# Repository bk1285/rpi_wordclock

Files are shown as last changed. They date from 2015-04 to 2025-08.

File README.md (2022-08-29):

## Software to create a Raspberry Pi based wordclock

### :vertical_traffic_light: Repo status

<p align="left">
 
 
 
</p>

### ✔️ Features
 * [Various language layouts](https://github.com/bk1285/rpi_wordclock/tree/master/wordclock_layouts)
 * [Various plugins](https://github.com/bk1285/rpi_wordclock/tree/master/wordclock_plugins) to
     * display the current time
     * get information on current temperature, sunrise, sunset, IP-settings, ...
     * play tetris (credits to [@mrksngl](https://github.com/mrksngl))
     * View a demo [here](https://youtu.be/wcLQDykRBbM?t=84)
 * RESTful, [swagger](https://swagger.io/specification/)-based API to access and control the wordclock functionality
 * [Documentation](https://rpi-wordclock.readthedocs.io/en/main/) on how to build the clock.
 * Remote control via webinterface (credits to [@FrankX0](https://github.com/FrankX0))
     * Control the wordclock with a browser within your local network
     * Linking the webinterface to your smartphones homescreen provides an app-like usage of the interface
     * Hardware buttons are not mandatory anymore.
 * Integration to your instance of [home-assistant](https://www.home-assistant.io/) using [this repository](https://github.com/bk1285/rpi_wordclock_for_homeassistant/)
 * Support for a brightness sensor (TSL2561)
  
### :books: Further reading
 * Exemplary builds are available at [pinterest](https://www.pinterest.de/berndkrolla/wordclock-gallery/)
 * [Roadmap](https://github.com/bk1285/rpi_wordclock/projects)

### 👏 Support 
 * Star this repo, if you like the project. 
 * Request a new feature by [opening a issue](https://github.com/bk1285/rpi_wordclock/issues), describing your feature request.
 * Contribute your code: [Learn how to create your own plugin](https://rpi-wordclock.readthedocs.io/en/master/doc_further_reading.html#adding-a-new-plugin)

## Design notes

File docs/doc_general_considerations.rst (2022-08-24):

.. _general_considerations:
General considerations
======================

.. _building_a_wordclock:
If you want to build a wordclock
++++++++++++++++++++++++++++++++

.. note:: This project is currently still in an experimental state:

  * The documentation contains the main steps to build a wordclock, but might not guide you through all steps in greatest detail
  * Depending on your language-dependent stencil-layout, you might need to adapt the software.
    Feel free to contribute here!
    Currently available:

      * Stancil layout and software:

          * german (including swabian and bavarian: Thanks to Timo and Euchkatzl)
          * english (Thanks to Alexandre)
          * dutch (Thanks to svenjacobi, resolution is 10x9. Therefore, not all plugins are supported!)
          * swiss
          * french
          * romanian (Thanks to Darius)
          * swedish

      * Stancil layout only (requiring some python-implementations: See wordclock_plugins/time_default):

          * italian
          * spanish
          * turkish

      * Further languages/stencil layouts can be created using the ''config-file'' and the script ''create_layout.py''

  * A final note: Throughout this project, you will assemble electronic components, which can possibly harm you or others (or destroy your hardware).
    It's therefore important, that you know, what you are doing: By assembling this clock, you act on your own risk!

* Hardware requirements:

  * A (wooden) sceleton to hold LEDs, stencil, RPi, etc...
  * A stencil providing the letters
    * Find an overview over the different layouts here: https://github.com/bk1285/rpi_wordclock/tree/master/wordclock_layouts
    * You can create them on your own: Special plotters can produce adhesive stencils, which you can glue onto a glas plane.
    * Consider, that you might need to invert the layout to have the adhesive surface on top to attach to the glas plate.
    * Possible options for ordering a stencil are:
      * https://www.ponoko.com/ (thanks to StefanCarton).
      * http://www.mikrocontroller.net/articles/Word_Clock (thanks to euchkatzl)
    * Further reading:
      * http://diskussion.christians-bastel-laden.de/viewforum.php?f=12&sid=b90281d4a392f47503e9b9fc15495b19

  * A frame to enframe the wordclock

    * Possible materials: Wood, alumnium, etc.

  * A LED-strip running at 5V (e.g. WS2812 B Stripe 5m 150 LED)

    * Assure, that the spacing of the LEDs on the strip is equal or greater than the spacing of the letters
      of your stencil. If the spacing is smaller, you will not be able to get your LEDs into the correct position.

  * A Raspberry Pi (e.g. Review B, including SD-card)
  * A wifi-dongle to connect your RPi wireless to your local network
  * A power supply (e.g. 5V 10A 50W LED Power Supply)

    * 5V are required. The current, which needs to be provided at max depends on the number and power consumption of you LEDs.

  * A user-interface to run the wordclock

    * e.g. 3 buttons (each requiring a 1k and a 10k resistor)
    * e.g. a capacitive touch sensor
    * ...

  * Some plugs to connect cables to the Raspberry Pis GPIO-pins
  * A micro-usb cable to connect the Raspberry Pi to the power supply
  * Optional: Hardware for levelshifting as oulined in https://learn.adafruit.com/neopixels-on-raspberry-pi/wiring and http://youtu.be/V9TwvranJnY?t=23m08s
  * Optional: A temperature sensor like an AM2302. To connect the sensor, an additial 10k resistor is required.

* You need to setup the software on your own

  * Some first documentation available here
  * This might require some python programming (to adopt the software to your needs)

* You should be ready to...

  * Setup the hardware (glueing, soldering, etc.)
  
    * Consider double connectors, if you want to minimize soldering efforts: https://github.com/bk1285/rpi_wordclock/issues/118
    
  * Setup a Raspberry Pi (raspbian)

    * Connect to the RPi via ssh
    * Install external dependencies of the wordclock project
    * Do some python programming (to adopt the software to your needs)

  * Contribute to this project

    * by sharing your implementations/improvements/enhancements/... ;)

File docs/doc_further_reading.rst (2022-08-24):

.. _further_reading:
Further reading
===============

.. _concepts:
Concepts and background
+++++++++++++++++++++++

.. _concept_WCA:
* WCA (Word Clock Array): The center matrix, without minute-LEDs and other stuff
.. _concept_WCA_DIMENSION:
* WCA_WIDTH, WCA_HEIGHT: Height and width of the WCA.

  * Part of the wordclock software are png-files, which need to fit to these values.
  * Currently available: 11x10 png-files.
  * Support for wordclocks with other resolution available (untested).

.. _concept_WCD:
* WCD (Word Clock Display): Includes any led attached to the wordclock (such as minutes, possible/future ambilights/etc.)
.. _concept_coordinate:
* Coordinates (or: WCA-coordinates): Can be 1d or 2d, used to adress a LED on the word clock array
.. _concept_index:
* Index (or: strip index): Used to adress a LED depending on the position on the LED-strip

.. _expanding_the_wordclock:
Expanding the functionality of the wordclock
++++++++++++++++++++++++++++++++++++++++++++

Remote control of the wordclock
-------------------------------

The wordclock comes with a REST-API to control the major functionality of the clock.

To access the API documentation, visit::

    http://wordclock-ip/api

Adding a new plugin
-------------------

You might be interested in expanding the wordclocks functionality by adding a new
plugin to the wordclock

To do so, you need to...

  * Think about the name of this plugin: E.g. `new_stuff`
  * Add a new folder `new_stuff` to the folder wordclock_plugins

    * Create a plugin.py-file with a class `plugin`, which has at
      least the following functions implemented:

      * __init__(self, config): You can use the config-object to pass data
        from the config-file for initialization purposes
      * run(): Run the actual plugin

  * For the actual implementation, you can access the provided methods of the class `wordclock_display`
    * If necessary you might extend it... ;)

  * Add an icon (with resolution 11x10 pixel) for the new plugin to the
    directory wordclock_plugins/`new_stuff`/icons/11x10/`logo.png`

  * Add a section `[plugin_new_stuff]` to the reference config-file (wordclock_config/wordclock_config.reference.cfg) and store there all necessary config-values in a way that they are suitable for all wordclock users by default and out of the box.
    * Even consider disableing your plugin by default..
    * Disabling is mandatory, if additional hardware is required to run the plugin.
  * Add the same section `[plugin_new_stuff]` to your local config-file (wordclock_config/wordclock_config.cfg), holding the (custom) values you want to have setup for your own clock.
    * Your plugin will extract config values from wordclock_config.cfg first. If they are not set their, it will default to wordclock_config.reference.cfg

  * Document everything properly, so that others (and maybe you as well) can later understand it... ;)

  * Commit your changes using git and consider to create a pull-request at https://www.github.com/bk1285/rpi_wordclock

  * Consider, that this repository uses nvie's branching model: http://nvie.com/posts/a-successful-git-branching-model/

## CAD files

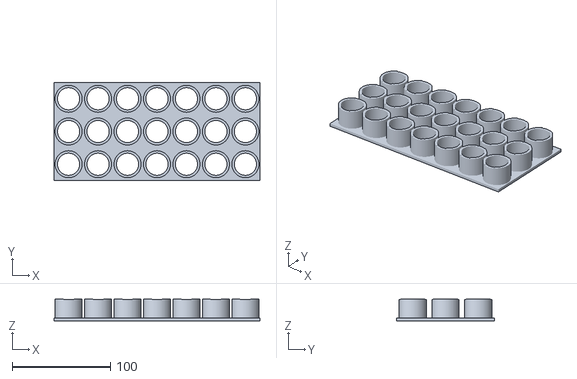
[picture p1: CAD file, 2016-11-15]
wordclock_layouts/wordclock_sceleton/LED-Base--LED-Mount-MM-Top.stl
209.7 x 99.7 x 22.0

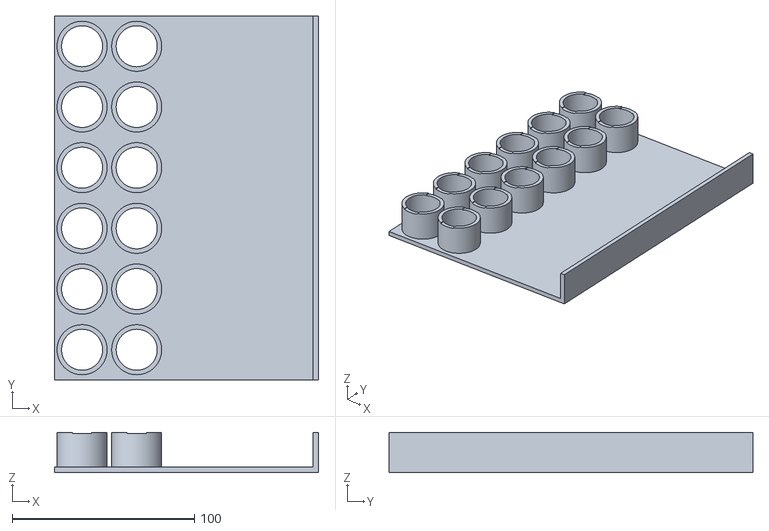
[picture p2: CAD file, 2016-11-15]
wordclock_layouts/wordclock_sceleton/LED-Base--LED-Mount-MR.stl
145.0 x 199.7 x 22.0

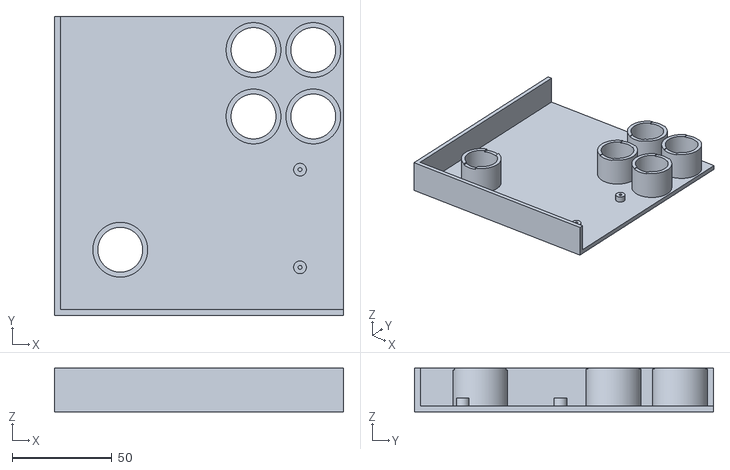
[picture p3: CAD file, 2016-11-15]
wordclock_layouts/wordclock_sceleton/LED-Base--LED-Mount-BL.stl
145.0 x 150.0 x 22.0

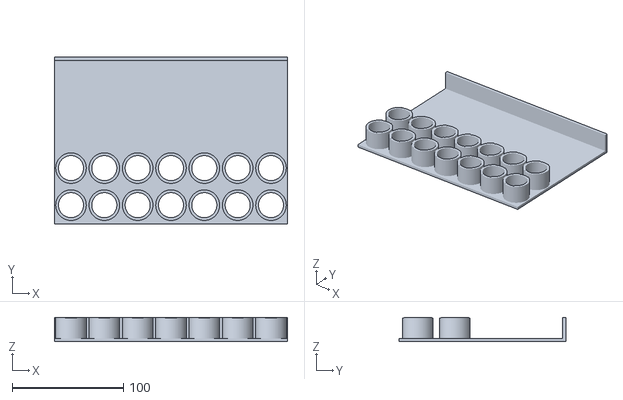
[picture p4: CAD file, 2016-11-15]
wordclock_layouts/wordclock_sceleton/LED-Base--LED-Mount-TM.stl
209.7 x 150.0 x 22.0

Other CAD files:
wordclock_layouts/wordclock_sceleton/LED-Base--LED-Mount-MM-Bot.stl
wordclock_layouts/wordclock_sceleton/LED-Base--LED-Mount-BR.stl
wordclock_layouts/wordclock_sceleton/LED-Base--LED-Mount-BM.stl
wordclock_layouts/wordclock_sceleton/LED-Base--LED-Mount-ML.stl
wordclock_layouts/wordclock_sceleton/LED-Base--LED-Mount-TR.stl
wordclock_layouts/wordclock_sceleton/LED-Base--LED-Mount-TL.stl

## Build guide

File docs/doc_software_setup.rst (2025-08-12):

.. _software_installation:

Software setup
==============

Setup your raspberry pi 
+++++++++++

Setup your raspberry pi (e.g. using Raspberry Pi Imager) by downloading and installing latest Raspian on the SD card.

During the installation process, configure the location according to your needs (incl. time zone, etc.) 

Set locales
+++++++++++

Since the config-file contains layouts for multiple languages, assure to have a utf-8 compatible locale after setting up your raspberry::

    echo $LANG

should return something, containing utf-8 at the end.
E.g.::

    en_US.UTF-8

If not, check this website, to adjust it: http://perlgeek.de/en/article/set-up-a-clean-utf8-environment

.. _wordclock_software:

The wordclock software
++++++++++++++++++++++

.. _3rd_party_deps_packages:

3rd party dependencies (packages)
---------------------------------

To install 3rd party dependencies (packages) enter in a terminal/commandline::

    sudo apt-get install git python3-pip python3-scipy swig fonts-freefont-ttf libopenjp2-7

.. _download_software:

Download software
-----------------

Clone the wordclock software to the directory ~/rpi_wordclock (to run the actual wordclock)::

    cd ~
    git clone https://github.com/bk1285/rpi_wordclock.git

.. _temperature_sensor:

(Optional) dependencies to readout temperature sensor
-----------------------------------------------------

To read out an temperature sensor (AM2302), which can additionally be connected to the raspberry via GPIOs, install the according dependencies:

These dependencies are http://www.airspayce.com/mikem/bcm2835/index.html

and::

    sudo pip install am2302_rpi

.. _brightness_sensor:

(Optional) brightness sensor
----------------------------

For using brightness sensor (tsl2561) i2c must be activated via raspi-config::

    sudo raspi-config

use the arrow keys to select 'Interfacing Options' and 'I2C' to tell the RasPi to enable the I2C interface. Then select 'Finish' and reboot the RasPi

Install adafruit-circuitpython-tsl2561 lib::

    sudo pip3 install adafruit-circuitpython-tsl2561

Set use_brightness_sensor config value to true and its address::

    # Set the brightness of the display (between 1 and 255)
    brightness = 200
    use_brightness_sensor = True
    sensor_address = 0x39

.. _3rd_party_deps_python:

3rd party dependencies (python packages)
----------------------------------------

To install 3rd party python dependencies (packages) run::

    cd ~/rpi_wordclock
    sudo pip3 install -r requirements.txt

.. _adopt_software:

Adopt software
--------------

To adjust the wordclock to your own settings, create and edit the file ~/rpi_wordclock/wordclock_config/wordclock_config.cfg

To start over, you might just copy the file ~/rpi_wordclock/wordclock_config/wordclock_config.example.cfg and adopt this file.

Note: Each plugin of the wordclock project has its own section in the config-file (create it, if needed, but not existant)

.. note:: If your wordclock has a stencil layout or display resolution, which is not supported yet, you might need to adopt the
  software by providing your own `wiring`-class (to the file wordclock_tools/wiring.py)

.. _run_software:

Run software
------------

To run the wordclock software (with adapted wiring and config-file) do::

    cd ~/rpi_wordclock
    sudo python3 wordclock.py

In case, the whole thing is not working as expected: Maybe the section :ref:`trouble-shooting` might help...

Run software without hardware in developer mode with wxPython
----------------------------

To run the wordclock software in developer mode without wxPython, install wxPython via::

    sudo apt-get install python3-wxgtk4.0

and set the developer_mode to True in the config-file::

    developer_mode = True

and run the software with::

    cd ~/rpi_wordclock
    sudo python3 wordclock.py

.. _run_software_on_startup:

Make software run on every startup
----------------------------------

Add the python-script to crontab by calling the command::

    sudo crontab -e

Add here::

    @reboot sudo python3 /home/pi/rpi_wordclock/wordclock.py

Access the wordclock via webinterface
-------------------------------------

Visit the wordclocks webinterface by entering the wordclocks IP to your browers address bar.

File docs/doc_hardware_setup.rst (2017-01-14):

.. _hardware_setup:
.. _hardware_setup_steps:
Hardware setup
==============

.. _skeleton_setup:
Skeleton setup
++++++++++++++

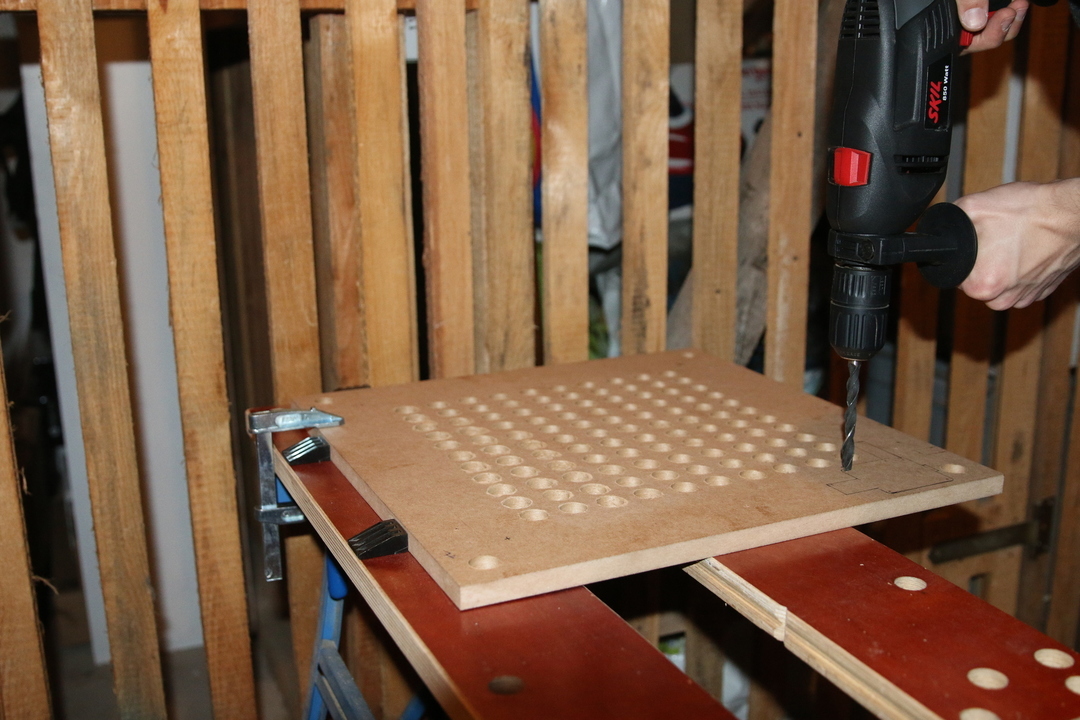
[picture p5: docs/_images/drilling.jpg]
Drilling


    According to the stencil layout, for each LED a hole needs to be prepared. The total number of 114 holes makes this pretty tedious.

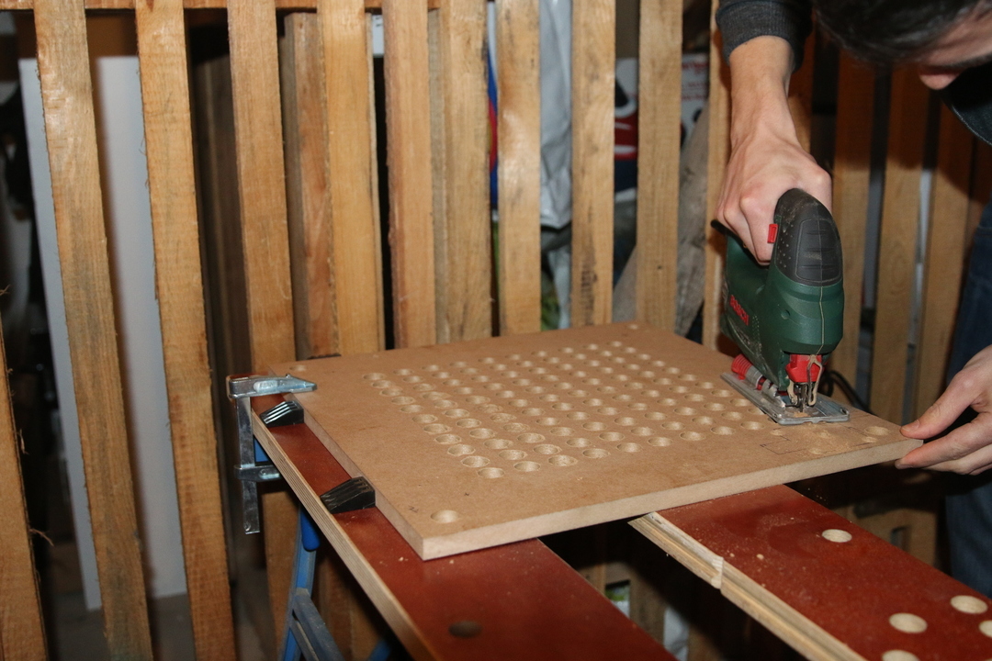
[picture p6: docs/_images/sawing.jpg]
Sawing


    To place the Raspberry Pi within the skeleton, some sawing is required...

.. _led_setup:
LED setup
+++++++++

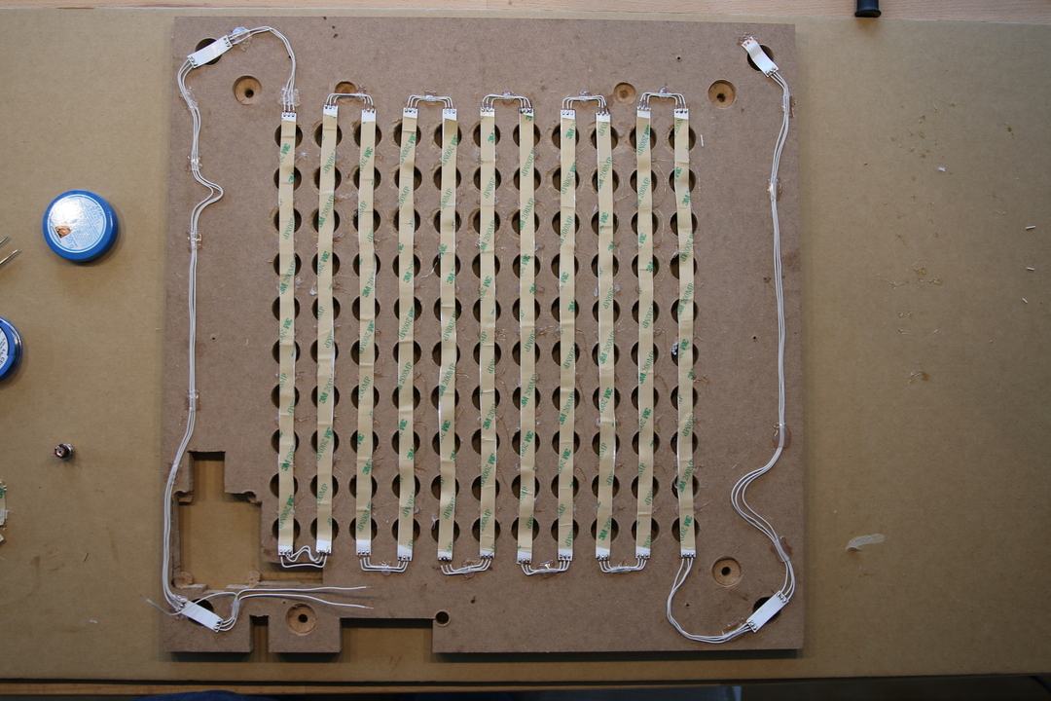
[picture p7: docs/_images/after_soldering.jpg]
After Soldering


    After soldering the LED strip, the clock looks like this. The soldering needs to be done according to the wiring layout. E.g. based on 11*10 letters:

.. _exemplary_wiring:
.. _concept_exemplary_wiring_layout:

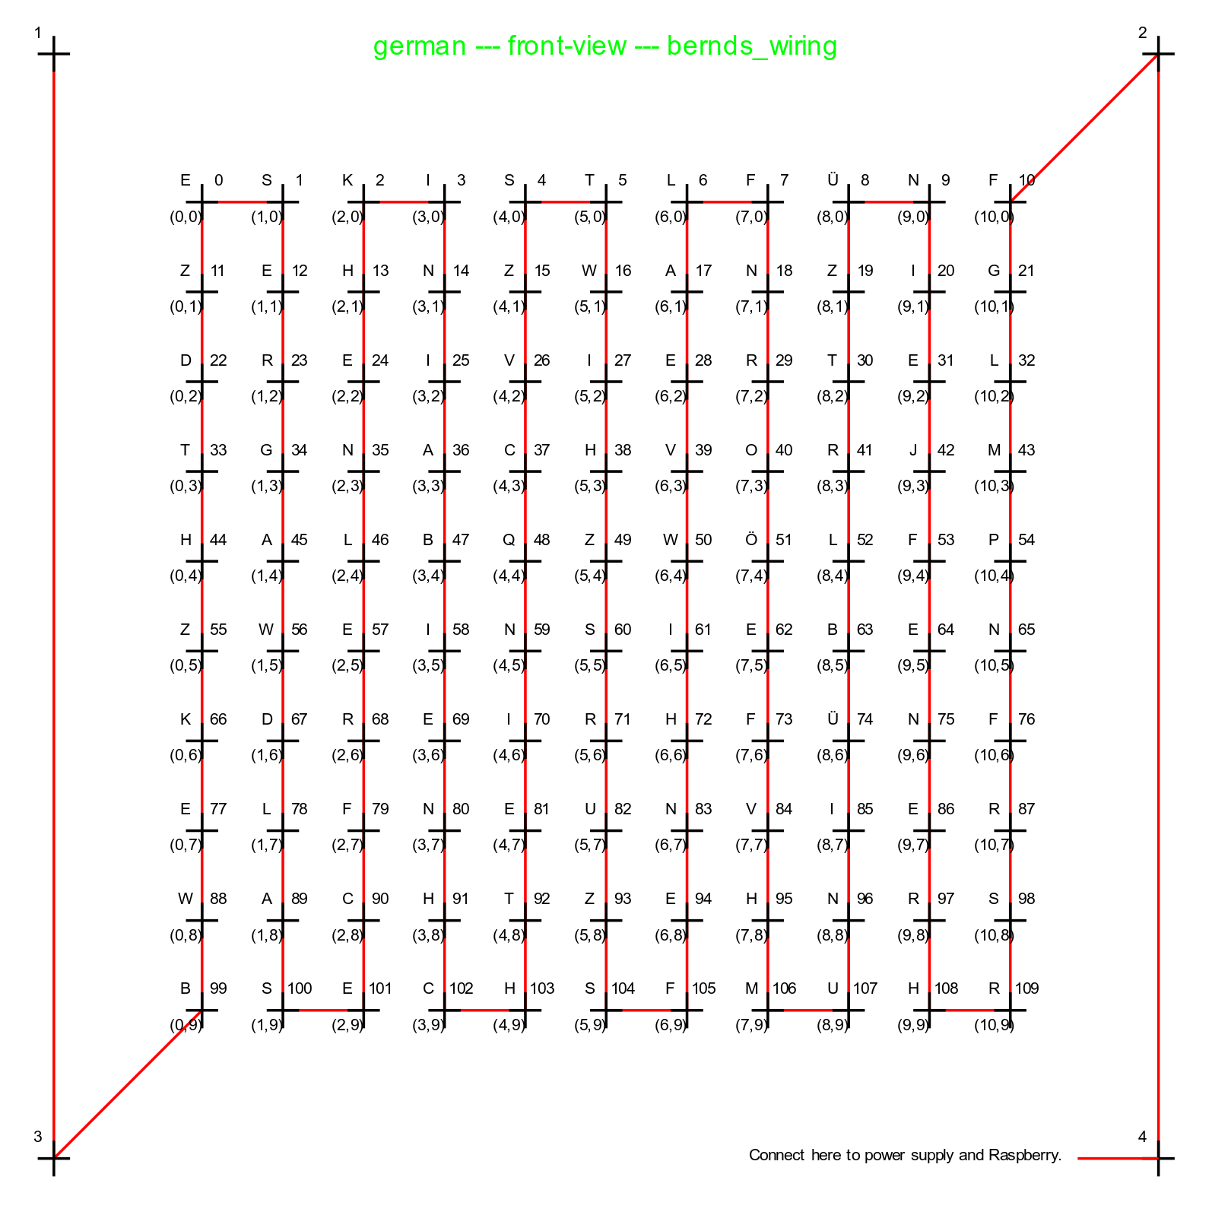
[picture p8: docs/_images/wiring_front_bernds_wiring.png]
Examplary wiring layout (front side)


    Further wiring layouts are `available <https://github.com/bk1285/rpi_wordclock/tree/master/wordclock_layouts>`_. Assure to connect the LED strip in the right direction. Little arrows indicate that along the strip.

.. _rpi_setup:
Raspberry Pi setup
++++++++++++++++++

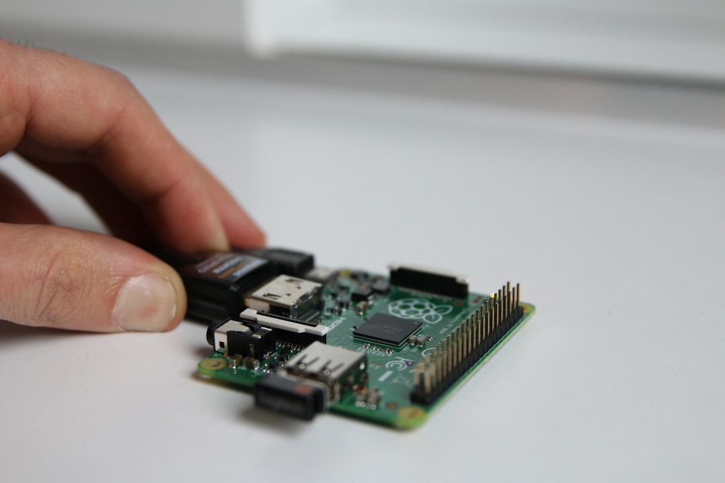
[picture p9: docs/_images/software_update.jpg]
Software Update


    Before you mount your raspberry inside the clock, install the latest Raspbian, connect it to your local wifi and ensure that you can ssh to it.

.. _button_setup:
Button setup
++++++++++++

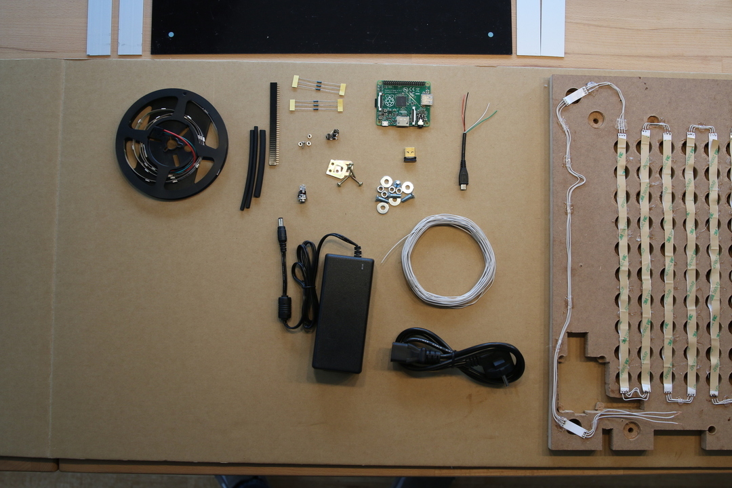
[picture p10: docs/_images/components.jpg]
Components


    At this stage, the displayed components are required for the further setup.

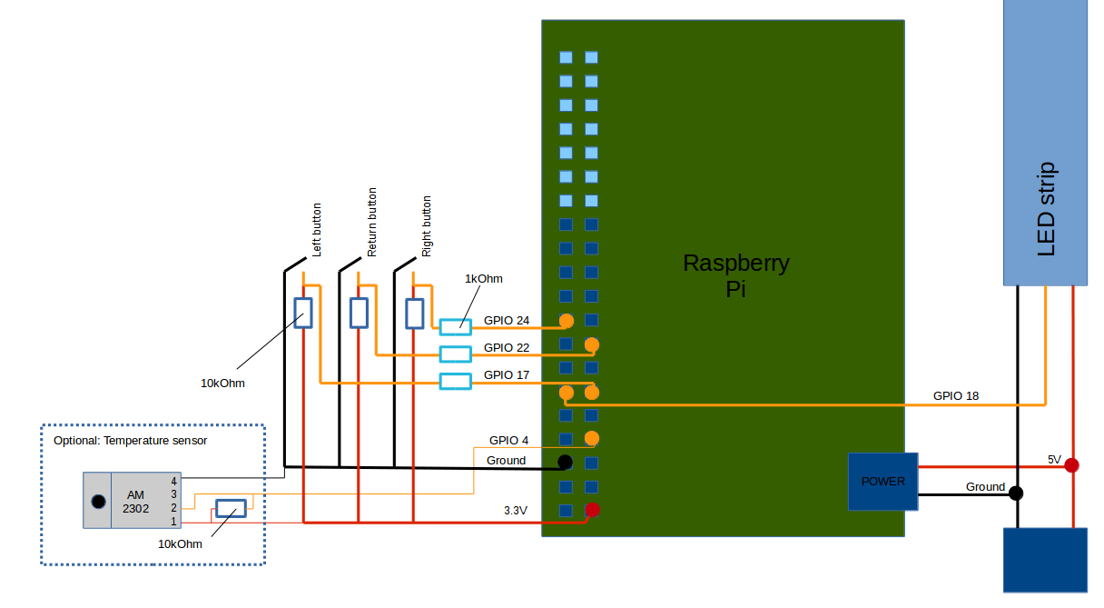
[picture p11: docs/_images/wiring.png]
Wiring concept


    Conceptual wiring layout to connect RPi, buttons, etc. See also `Power connectors <https://en.wikipedia.org/wiki/Coaxial_power_connector>`_, `USB-Pinouts <https://en.wikipedia.org/wiki/USB#Pinouts>`_

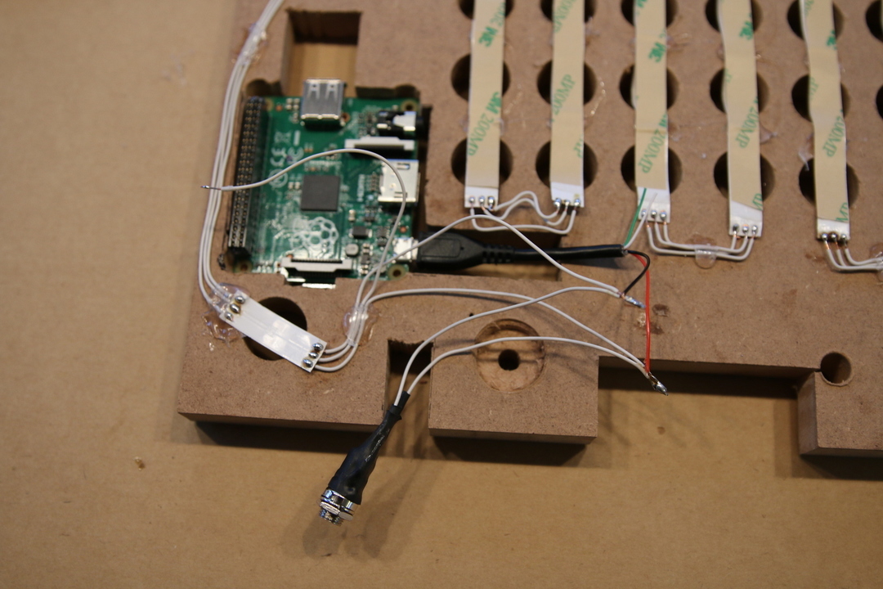
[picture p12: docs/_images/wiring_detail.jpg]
Wiring detail


    The connection of buttons, LED strip and power brings the wordclock close to its final hardware configuration.

.. _exemplary_button_wiring:

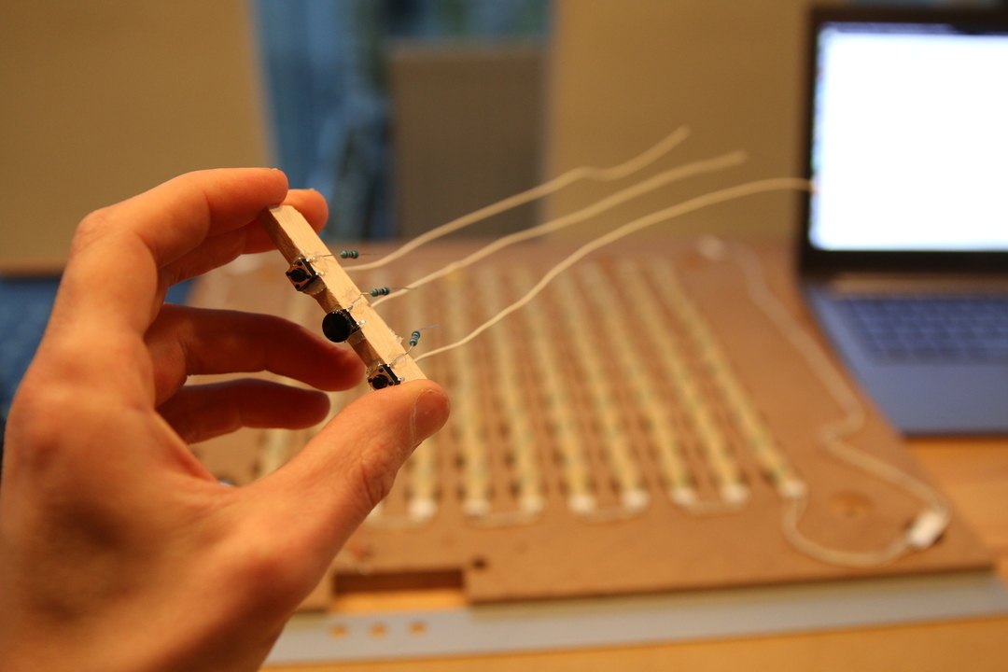
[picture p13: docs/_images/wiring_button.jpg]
Wiring button


    Buttons with attached resistors. The center button has already its final tip.

.. _stancil_setup:
Stancil setup
+++++++++++++

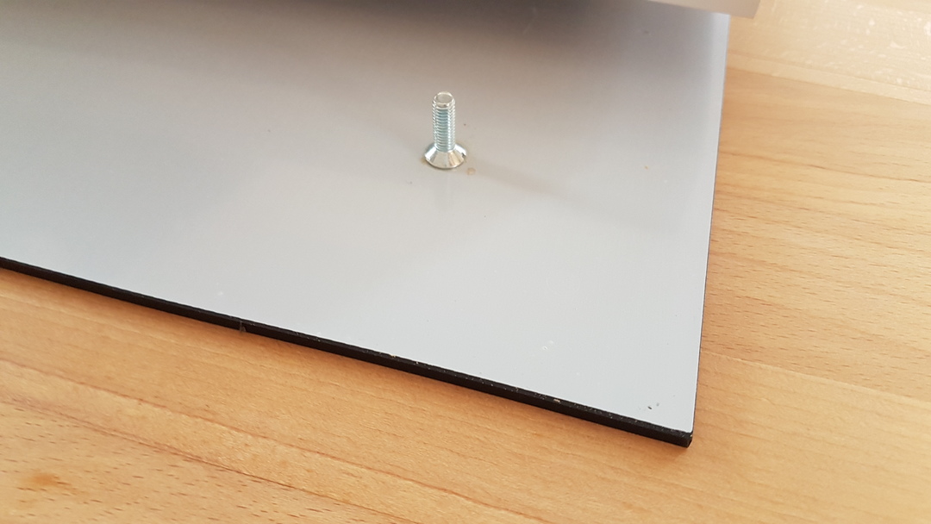
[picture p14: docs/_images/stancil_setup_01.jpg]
Stancil setup 01


    Fixation of 4 screws within the 4 corners of the stancil using two-component adhesive.

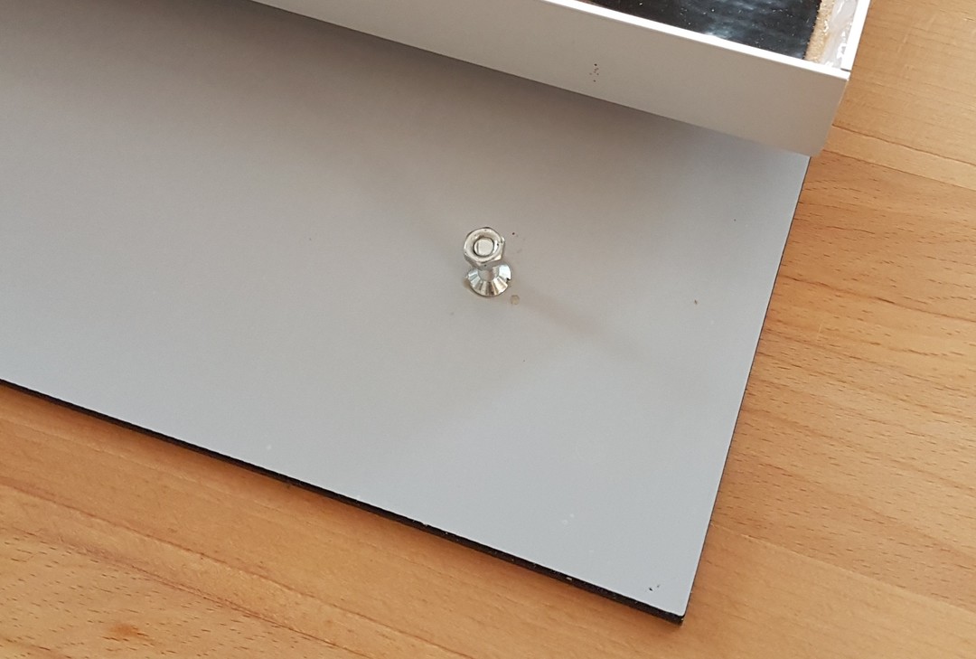
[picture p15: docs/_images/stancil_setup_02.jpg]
Stancil setup 02


    Allows to fix the stancil with screw-nuts to the sceleton.

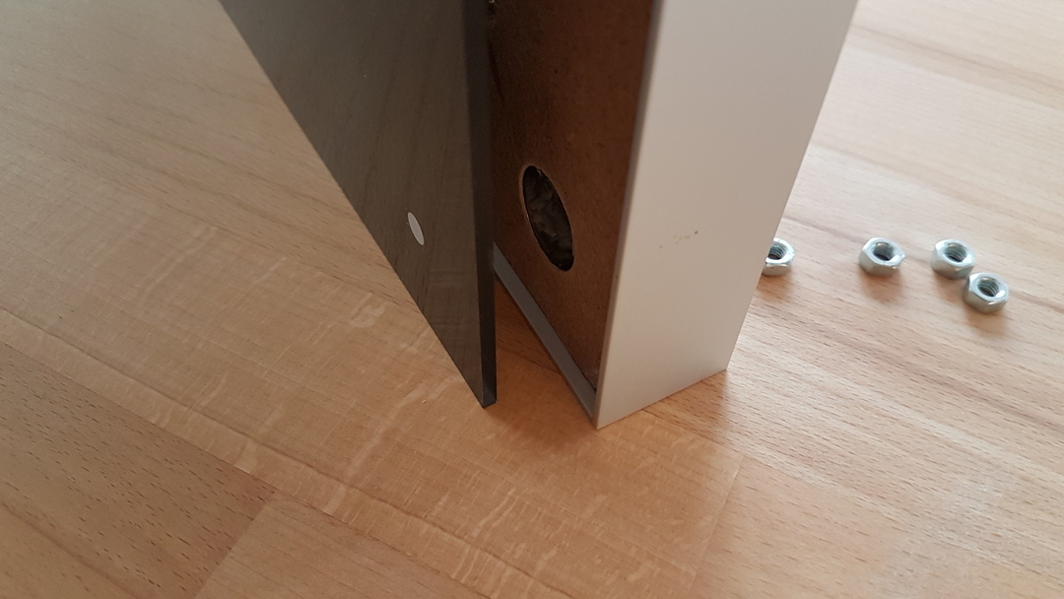
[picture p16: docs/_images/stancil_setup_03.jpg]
Stancil setup 03


    To increase stability, consider an overlapping of the frame to hold the major weight of the stancil.

.. _final_clock:
Final clock
+++++++++++

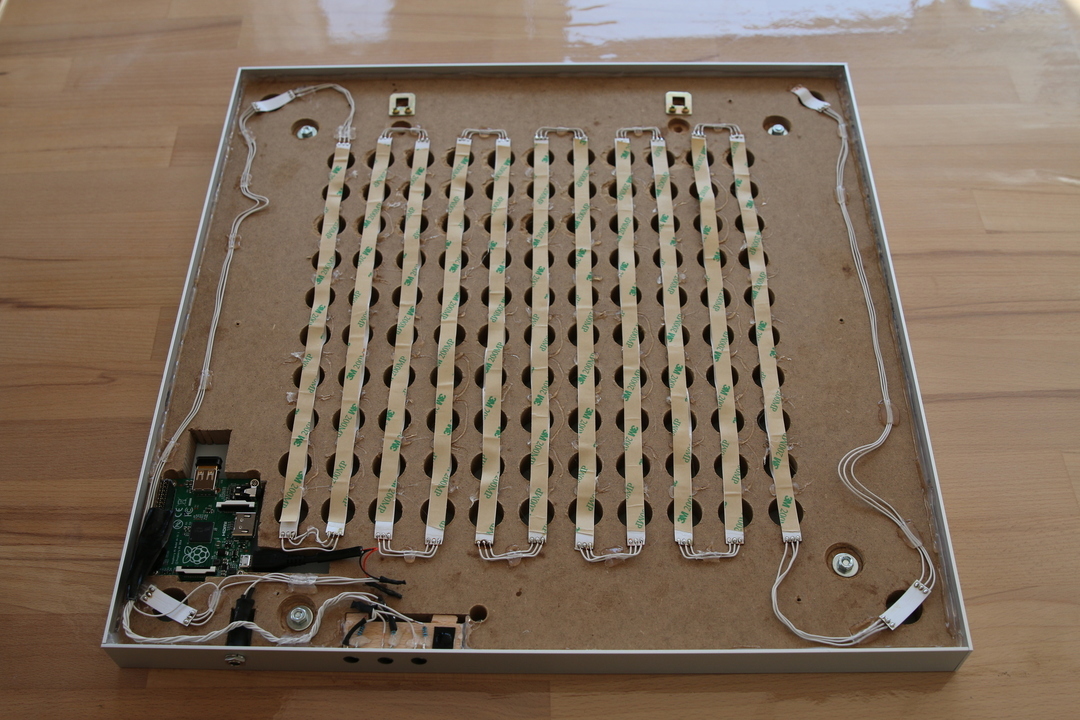
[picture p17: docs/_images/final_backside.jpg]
Final backside


    Backside of the final wordclock.

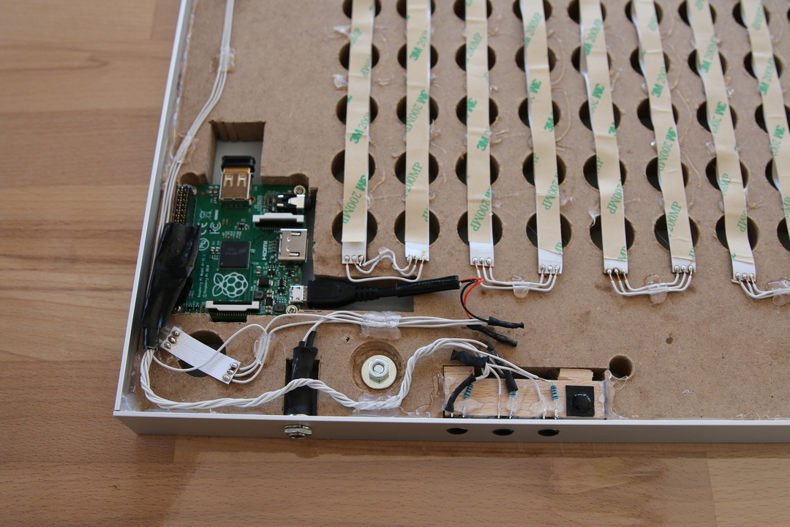
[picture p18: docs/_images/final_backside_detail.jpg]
Final backside detail


    Closeup of the final wordclock.

.. _video_documentation:
Video documentation on the wiring layout
++++++++++++++++++++++++++++++++++++++++

`Link to wiring documentation <http://youtu.be/V9TwvranJnY?t=8m43s>`_

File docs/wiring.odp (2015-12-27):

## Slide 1

3.3V

LED strip

Right button

Return button

5V

Left button

4

3

2

1

1kOhm

Raspberry Pi

10kOhm

GPIO 24

GPIO 22

GPIO 17

Optional: Temperature sensor

Ground

GPIO 4

GPIO 18

AM

2302

10kOhm

POWER

Ground

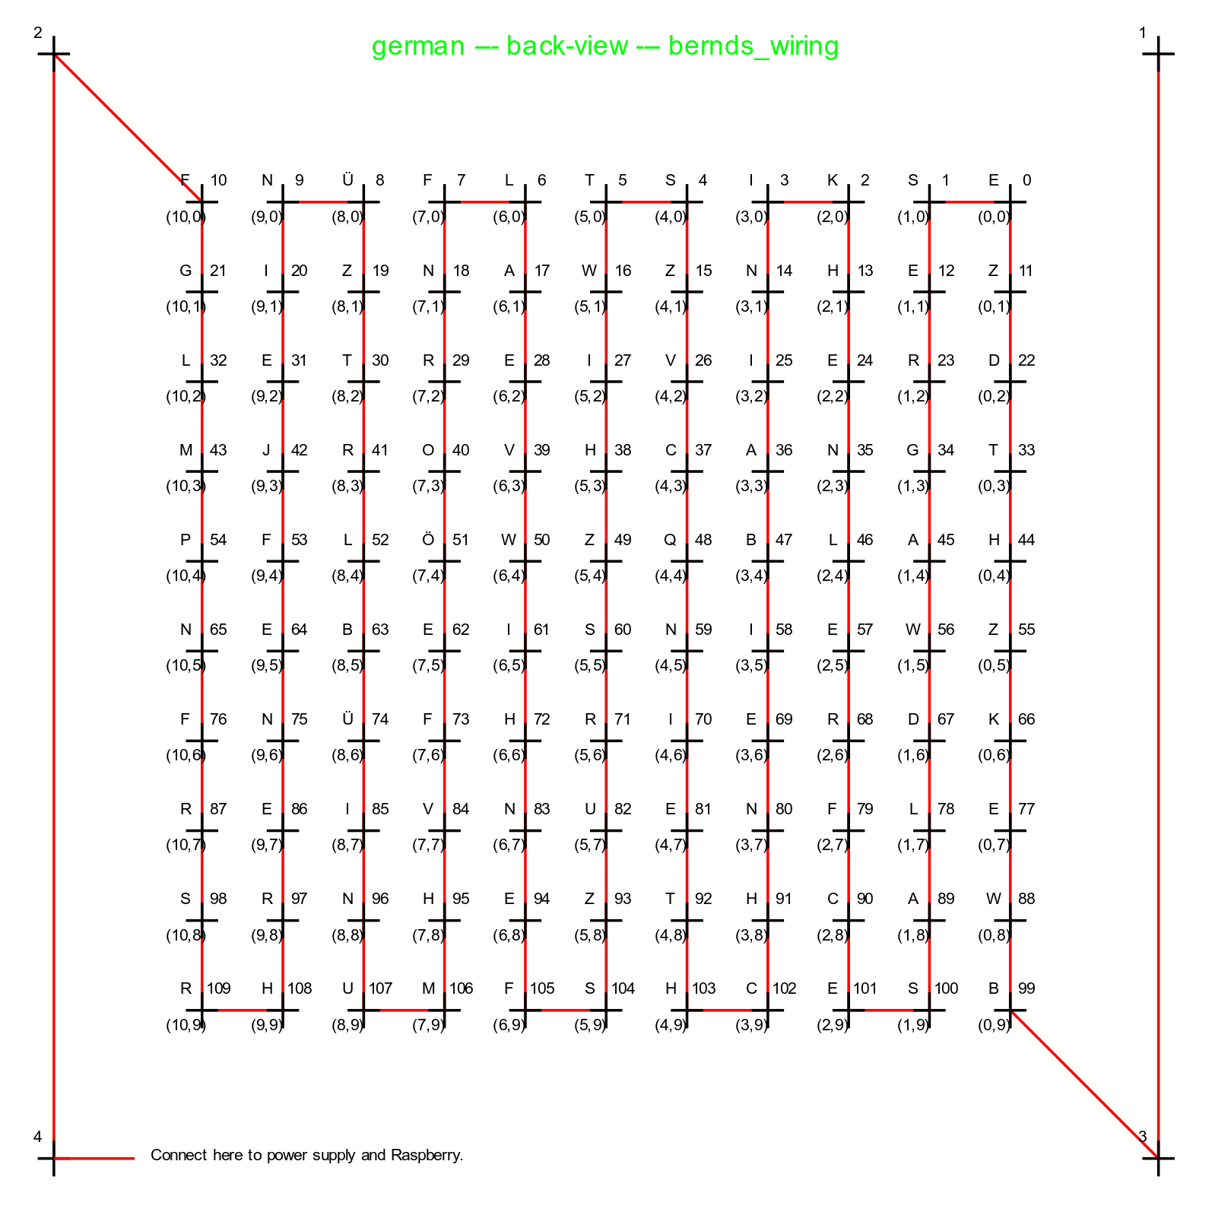
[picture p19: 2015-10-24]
docs/_images/wiring_back_bernds_wiring.png

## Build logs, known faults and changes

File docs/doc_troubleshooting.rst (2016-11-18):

.. _trouble-shooting:
Trouble shooting
================

Something is not working?

* The command::

    sudo pip install pytz astral feedparser pillow svgwrite freetype-py

  fails to install properly? If so, try to install further dependencies (thanks to SEBatHome)::

    sudo apt-get build-dep python-imaging libjpeg8 libjpeg62-dev libfreetype6 libfreetype6-dev

* The leds do not light up as expected?

    * It is important to have common ground for LEDs and RPi. Assure, ground is same for all of them (Thanks to euchkatzl).

    * Assure to connect the LED strip in the right direction. Little arrows indicate that along the strip (Thanks to euchkatzl).

    * Assure correct functionality of leds::

      cd ~/rpi_ws281x/python/examples
      vim strandtest.py # Set number of leds, pin, etc.
      sudo python strandtest.py

      The leds should light up now...

    * Disable the RPis soundcard (since it might interfere with the PMW-channel, sending data to the LEDs. Thanks to ELViTO12 for reporting)::

        sudo sh -c "echo blacklist snd_bcm2835 >> /etc/modprobe.d/alsa-blacklist.conf";
        sudo reboot;
        
    * In case the LEDs are flickering as shown in this video https://www.youtube.com/watch?v=UHxVS8SkXOU (Thanks to oxivanisher), consider the usage of a level-shifter to connect the GPIO-pin of the raspberry to the LED-strip. Further reading: https://github.com/jgarff/rpi_ws281x/issues/127 https://github.com/bk1285/rpi_wordclock/issues/38
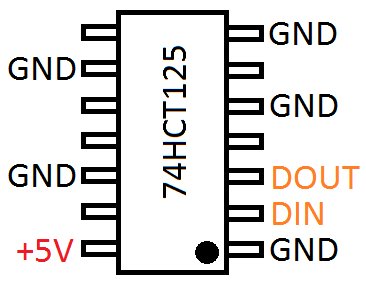
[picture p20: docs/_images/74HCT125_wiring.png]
Wiring of the a 74HCT125 level-shifter
    

* When starting the wordclock-script, "Pin 17 pressed" is logged all the time?

    To get rid of this message, you first need to finish the wordclock setup by attaching all 3 buttons to it.

    If you aim to run the wordclock without buttons, change the config-file settings as follows::

      [wordclock_interface]
      type = gpio_high

.. note:: The provided information might be completely unsatifying, leaving you here frustrated and annoyed without a working wordclock... :/

 However, if you have any issues during the setup, consider:

 * To update the provided documentation (or this trouble shooting section), as soon as you resolved your problem.

 * To report a software issue here: https://github.com/bk1285/rpi_wordclock/issues

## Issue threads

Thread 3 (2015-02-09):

Schaltungsvariante "spiegelverkehrt"

ghwc2015, 2015-02-09:
Hallo Bernd,

beim Zusammenlöten meiner Matrix habe ich nicht darauf geachtet, dass deine Bilder unter Concepts und wiring layout von hinten abgebildet waren.
Meine Variante benötigt daher eine spiegelverkehrte wiring.py

Habe diese erstellt und würde mich freuen wenn du die in den Code einbauen kannst - dann kann ich mit git zukünftige Änderungen mitbekommen.

```

class timos_wiring:
    '''
    A class, holding all information of the wordclock's layout to map given
    timestamps, 2d-coordinates to the corresponding LEDs (corresponding to
    the individual wiring/layout of any wordclock).
    If a different wordclock wiring/layout is chosen, this class needs to be
    adopted.
    '''

    def __init__(self):

        # LED strip configuration:
        self.LED_COUNT   = 114     # Number of LED pixels.
        self.LED_PIN     = 18      # GPIO pin connected to the pixels (must support PWM!).
        self.LED_FREQ_HZ = 800000  # LED signal frequency in hertz (usually 800khz)
        self.LED_DMA     = 5       # DMA channel to use for generating signal (try 5)
        self.LED_INVERT  = False   # True to invert the signal (when using NPN transistor level shift)

        self.WCA_WIDTH   = 11      # Wordclock array width
        self.WCA_HEIGHT  = 10      # Wordclock array height

    def setColorBy1DCoordinates(self, strip, ledCoordinates, color):
        '''
        Linear mapping from top-left to bottom right
        '''
        for i in ledCoordinates:
            self.setColorBy2DCoordinates(strip, i%self.WCA_WIDTH, i/self.WCA_WIDTH, color)

    def setColorBy2DCoordinates(self, strip, x, y, color):
        '''
        Mapping coordinates to the wordclocks display
        Needs hardware/wiring dependent implementation
        Final range:
             (0,0): top-left
             (self.WCA_WIDTH-1, self.WCA_HEIGHT-1): bottom-right
        '''
        if x%2 == 0:                    # even columns 0,2,4...
            pos = (x)*self.WCA_HEIGHT+y+2               # last +2 for the minute LEDs before the WCA
        else:                           # odd columns 1,3,5...
            pos = (self.WCA_HEIGHT)+(self.WCA_HEIGHT*x)-y+1

        strip.setPixelColor(pos, color)

    def mapMinutes(self, min):
        '''
        Access minutes (1,2,3,4)
        Needs hardware/wiring dependent implementation
        This implementation assumes the minutes to be wired as first and last two leds of the led-strip
        '''
        if min == 1:
            return 1
        elif min == 2:
            return 113
        elif min == 3:
            return 112
        elif min == 4:
            return 0
        else:
            print('WARNING: Out of range, when mapping minutes...')
            print(min)
            return 0

    def getMinuteIndices(self):
        '''
        Returns all indices of the led strip, which are representing minutes
        .. todo:: Merge/unify with mapMinutes
        '''
        return [1, 113, 112, 0]

    def getWcaIndices(self):
        '''
        Returns all indices of the led strip, which are part of the word clock array
        '''
        return range(2, self.LED_COUNT-2)

```

bk1285, 2015-02-17:
Hi Timo,
if I got it right, is this issue related to https://github.com/bk1285/rpi_wordclock/issues/4
Therefore, I'll close this one, adding your wiring layout.
For future contributions I obviously prefer pull requests instead of sourcecode via issues... ;)
Regards,
Bernd

Closed 2015-02-17.

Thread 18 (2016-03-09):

Remote Control

euchkatzl, 2016-03-09:
I have created an experimental iOS App to Control the Wordclock from your smartphone. (Needs Xcode to Compile and Run)

Check it out here :

https://github.com/euchkatzl/RaspberryWordclock-iOS

bk1285, 2016-03-12:
Hi @euchkatzl ,

That's a great thing! I like it a lot! I shortly inspected your repository and saw, that some diff needs to be applied to the wordclock installation in order to make it work with the app...

Maybe we should team up to modify the wordclock to be iOS-ready by default... ;)

I'd even consider one "global" solution, which considers android as well. I'll take a closer look, if I find the time: Probably not within the next two weeks... :/

Meanwhile I leave this issue open.

Best,
Bernd

euchkatzl, 2016-03-14:
I'm am already working on a better solution.

The best solution will be a simple web site hosted by the pi accessible through a normal web browser.

I have little experience with that but i will get this work i think.
I will post it here as soon as possible.

Would be great if you could apply this patch by default.

euchkatzl, 2016-03-16:
I have made the Web based solution.
Check it out : https://github.com/euchkatzl/RaspberryWordclock-RemoteControl.

My main Problem is that i cannot test all this stuff because the clock was a present for christmas and i have no possibility to give it a "live" try at any time. I will build mine in the course of this year.

Will be great if we get this working.

euchkatzl, 2016-10-02:
Hi Bernd,
finally  created my own clock and get the remote stuff working. (On all devices ;) )

Can you please check out the changes in my Repository and perhaps include it ? (https://github.com/euchkatzl/RaspberryWordclock-RemoteControl)

It is really cool playing tetris with controlling from your smartphone ;)

bk1285, 2016-10-02:
Awesome! I need to check this out!

I'll definitely add it to the repository! But tell me: Do your virtual GPIOs interfere with the real buttons?

Regards!
Bernd

euchkatzl, 2016-10-02:
No. The real buttons work like before. They have the same functionality.

Look at wordclock_interface.py file.

It is just and "or" clause.

SimJaaenis, 2016-11-15:
Does it work at the moment? I tried it, but when I start the Webiopi-deamon I'm not able to use any button at the clock or at the web-interface.
I read, at the RaspberryWordclock-RemoteControl-project, you are using the Pins 7, 8 and 11.
If you are referring on this wordclock-project, shouldn't it be Pins 11, 15 and 18?

euchkatzl, 2016-11-15:
Yes it works for me !
I have choosen GPIO's 7,8 and 11 (that is not the pin number! There is a difference. pin numbers for the Remote Control are 23,24 and 26). Of course you can use any other GPIO's. But then you have to modify the patch file and the index.html in my repo.
GPIO 18 you cannot use because it is used for the LED signal.

What did you do so far ? Did you see my Web Interface that i have written ?
Have you applied the patch file to the wordclock repo ? It is not included by default

SimJaaenis, 2016-11-16:
Referring to this image [http://rpi-wordclock.readthedocs.io/en/latest/_images/wiring.png](url) I did my wiring.
Left button is at GPIO 17 = Pin 11, return button is at GPIO 22 = Pin 15 and  the right button is at GPIO 24 = Pin 18.
Just to understand the functionality: Do you use the same GPIO's like the original (hardware) buttons, or are the virtual "buttons" just referring to the same functionality as the hardware buttons?

Yesterday I saw your edited index.html with the "wordclock" link. Now I'm seeing the default page, without the link. I tried to many different things to get this to work, now its better if I clean install my wordclock.

euchkatzl, 2016-11-16:
The virtual buttons have only the same functionality as the original buttons.

But I think there is a wrong path file in the repo.
I will check this as soon as i am at home today.

euchkatzl, 2016-11-16:
i created a fork with all the changes :
https://github.com/euchkatzl/rpi_wordclock (Commit : 0846e15d1ce63b189e55d58257882202ac61cf84)

euchkatzl, 2016-11-16:
You can simply clone ist to another folder.
Then link the fontdemo.py and the this should work if you have configured webio-pi the right way.

I have tested this just right now ;)

bk1285, 2016-11-16:
Great, @euchkatzl,  Just merged it back: https://github.com/bk1285/rpi_wordclock/pull/39

bk1285, 2016-11-16:
@SimJaaenis can you confirm, if it works. If this is the case, I'll close the issue.
Bernd

SimJaaenis, 2016-11-17:
Short answer: Now It works! Thanks a lot!
Long answer: @euchkatzl In my case, I thought the htdocs-folder is the default of WebIOPi's-Webinterface, but WebIOPi doesn't use the "../htdocs/index.html" as default. After I tell WebIOPi in its config to do that, it worked.
I wondered a few times, why my browser didn't show any change of the index.html in 'htdocs'. After I changed the config-file to exactly that directory, it worked.

`# Use doc-root to change default HTML and resource files location
doc-root = /home/pi/WebIOPi-0.7.1/htdocs`

Thanks a lot! Now I can play Tetris :D

A little improvement proposal:
an inactivity-time of the virtual buttons of 0.2 secs, after a virtual-button was pressed, would be good. Just like the hardware Buttons ;)

euchkatzl, 2016-11-17:
Great !
@SimJaaenis
The timeout is 150 ms (look in the index.html). For the virtual buttons we have to simulate this.
Try setting it to 200 an report if it improves your stuff.

SimJaaenis, 2016-11-20:
I think the problem is my WiFi.
I changed the position and now it works better without any code changes.

bk1285, 2017-01-04:
Refering to https://github.com/bk1285/rpi_wordclock/issues/57

... whats the best way to go? If we find a fix for the current master branch, which leaves the virtual pins enabled, we're done at first place.
In the long run we could probably consider something more advanced...

bk1285, 2017-01-04:
Maybe we could also consider the work of @fecub which looks preety promissing...  https://github.com/fecub/rpi_wordclock/commits/remote_controller

;)

Tihmann, 2017-01-08:
How does @fecub modification work ? Is it setting up a server ? Tried to figure it out from the branch....

euchkatzl, 2017-01-09:
@Tihmann
Can you tell me why Web IO Pi is not working anymore ?

bk1285, 2017-02-04:
Last weekend, I found the time to team up with @mrksngl, who is giving lectures in multi-threading, event-handling, etc. As a result of 14hrs of hacking, the wordclock will soon be ready to take not only the buttons as input anymore... Great work, @mrksngl :)

Checkout https://github.com/bk1285/rpi_wordclock/tree/develop for further details or take a look at https://github.com/bk1285/rpi_wordclock/projects/2 for the further agenda.

euchkatzl, 2017-02-07:
Hi @bk1285 ,

That is great work ! Thank you for that.
I've testet the socket connection with a litte Qt Programm. Seems to work fine !

But there is a little more work to do so that we can use it as Remote Control !

1. Add a command for Button press (e.g. sending  "BUTTON_PRESS" : 18)
    a.  I think that will not be the problem and very easy to implement
2. To work with any devices we need an web interface (like the page i have written)
    a. This page must be hosted on the pi to interact with the socket connection
    b. We need a web server on the pi
         1. Host it directly via python code ( i dont know if this is possible)
         2. Host it via node (i think this is the easiest solution)
         3. Set up an apache Web Server for usage of php
3. Without a new Webinterface the socket connection could only be used directly in an app that we habe to write for ios and android. I can do this but then we need to upload it to the app stores so that anybody can use it ( could be a problem . Especially on ios)

So tell me what you think the best solution could be !? I can do the Web Interface work if you want to.

fecub, 2017-02-07:
Hi @bk1285,

thank you Bernd. Thank you for this awesome clock project.
I wanted to report you, if I'm done with my work :) but you discovered me earlier :)

Ok what I have done:

-  as @Tihmann says. I set up an server and intergrated in the project.
- the remoting is working on main  menu, time_default and matrix plugins
- ... the other plugins need to modified for remoting
- I wanted the gpio button and remote controller things seperated. But this forcing me to add two or more lines of code

1. For example you need to pass the socket class on every plugin
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
mrksngl, 2017-02-07:
Little preview of my current work (yes, I emulated everything in here) (yes, GTK has some problems with umlauts): https://www-user.rhrk.uni-kl.de/~mengel/wclremote.webm

euchkatzl, 2017-02-07:
@bk1285 @mrksngl

I totally agree on the "bad design" points ! The solution now is a much better approach !

For App Developments i can help you since i'm am an app developer (iOS and Android) in my main job ;)

Video of the App looks great ! How did you get that simulated wordclock interface ? Can you explain that (perhaps in another ticket)

For the Android app you are right ! You can distribute this without any App Store. But in iOS this is not possible.

So the best approach is to write a new Webinterface which works with both systems (and also Windows Phone). I can do this as soon as you publish your Android Code.
Moved discussion for this :
https://github.com/bk1285/rpi_wordclock/issues/59

mrksngl, 2017-02-07:
@euchkatzl

Glad to hear we have an app expert:
1) I don't like GUI development at all (though I have to admit that android has some nice concepts and there is a really cool tool support in android studio)
2) I just started android development, so I read some guidelines (you know it: android is a beast) and realized the project "my own way". Especially data exchange between the network and the UI thread is maybe not the Android way.

The simulated wordclock interface is just a GTK window with a 11x10 table (plus the dots for the minutes), having 114 labels, each displaying one character. I replaced (it's a huge hack!) everything that has to do with the LED strip with GTK code recolouring the labels. The button events are generated by keyboard events. I could publish it, but only in a separate branch, because right now it breaks normal operation. This is another issue in refactoring the project.

euchkatzl, 2017-02-07:
1. Yes Android is very easy for GUI things. Much better than iOS.
2. I can tell you that when i got a look at your Code. For me it would be nice to get an idea how to talk to the socket ;)

The better approach would be using PyQt for the simulated GUI. So it works also on non Linux Systems (maybe). But would be great if you could publish it ;)
Thank you !

bk1285, 2017-11-03:
Hi all, just finished an experimental version of the webinterface: https://github.com/bk1285/rpi_wordclock/tree/feature/webpy
There are still some minor issues to fix, before I merge to develop, but maybe you want to give it a try (after installing web.py). Please note, that this currently requires the wordclock.py to be started within the directory, it's located in: /home/pi/rpi_wordclock.

Best,
Bernd

Sauerland1973, 2017-11-09:
Hallo Bernd,
habe dein Projekt noch ein wenig "verfeinert" ;-) Ich habe eine Matrix von 15 x 15 LED....
nun würde ich gerne auch das Web interface nutzen, allerdings bekomme ich diese Fehlermeldung:
File "/home/pi/rpi_wordclock/wordclock_interfaces/web_interface.py", line 1, in <module>
    import web
ImportError: No module named web

Was mache ich Falsch?
LG aus dem Sauerland

euchkatzl, 2017-11-09:
Du musst WebPy installieren :
http://webpy.org/install

Sauerland1973, 2017-11-09:
Oh, das ging schnell, vielen Dank für die schnelle Antwort!
Ich werde es direkt mal ausprobieren ;-)
LG

Closed 2018-01-04.

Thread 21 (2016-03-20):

Need help

christiankrueger16790, 2016-03-20:
Hi all,

Sorry, if i write down my comment into the wrong directory, but didn´t found a directory for questions.

I´m also want to build a RPi wordclock. I´ve got a rpi a+ model with ws2812 led controller.
Unfortunately, I'm still a little inexperienced in matters of led-controlling with a raspberry pi.
I´ve finished the hardware setup and installed the software like the description.
But when i´m start the wordclock software the leds, do nothing.
I´ve tried to controll the strips with the strandtest.py software, but the leds do also nothing.
Only two leds in the middle of the strips lights up.
I thought i´ve got a misstake in the wiring, but i´ve checked all the solder joints and i think there look good.
I tried to wired up the wordclock with a 74AHCT125 level converter and a 1N4001 diode like the description of (adafruit).

Can you give me an idea, what i also can check.
Sorry about my stupid questions and bad english!
I hope you can help me.

bk1285, 2016-03-20:
Hi @christiankrueger16790

hm... What do you mean with ws2812 controller? You just need to connect a WS2812B led-stripe to the Raspberry.

Ideas from my side:
- ensure to have a WS2812B led strip (no WS2812: This is untested and possibly does not work)
- ensure to have the correct number of LEDs set to trigger (adopt the strandtest.py)
- ensure to have a power supply, which supplies enough power: With 10A at 5V, you're on the save side.

If you find the solution, maybe just post it here, so that others can benefit as well. Hope that helps. Otherwise, just reopen the issue.

Regards,
Bernd

christiankrueger16790, 2016-03-22:
Hi Bernd

Sorry, but it is a ws2812B led stripe, not only ws2812.
I set the correct number of leds (114 counts).
I´ve got a power supply of 5V/10A, i think that´s ok.

Do you have another idea?

Can create and upload a zip file of your actual wordclock image with win32 disk manager, is it possible?
Because I want to ensure, that i don´t forgot any packages.

Regards
Christian

bk1285, 2016-03-22:
Hm.... maybe try to go through the installation steps again: If you reinstall the packages, you might identify missing dependencies...

Regards,
Bernd

Closed 2016-03-20.

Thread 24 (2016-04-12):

stencil/clock face

whybot, 2016-04-12:
Hello,
Are you able to provide link(s) to online vendors who can produce customised stencil/clock faces perhaps the online company used for this? -might be useful to add to the hardware list in the documentation.
Thanks :)

stefancarlton, 2016-04-12:
I used https://www.ponoko.com/ for my clock face in wood. They were very helpful in getting my layout in the correct format for their printers.

bk1285, 2016-04-13:
Thanks @whybot and @stefancarlton for the hints. I'll add it to the documentation.
Regards,
Bernd

bk1285, 2016-04-13:
... why not wait for possible further comments and ideas... ;)

i-pinz, 2016-07-31:
Hello Bernd,

What is the size of the wooden board you used? And the framing is done with alu-profiles or did you had a frame from an picture-frame. Your project looks nice, and I'm just collecting the pieces I need to make a shopping tour. What I miss is a some kind of measurement of the frame and the wooden board.

Thanks
pinz

bk1285, 2016-07-31:
Hi @i-pinz,

I used alu profiles. The wooden board needs to have the same size as your stancil. To make the alu-profiles fit, consider that they need to overlap at the corners. Hope, that helps?

Regards,
Bernd

i-pinz, 2016-07-31:
Hi Bernd,

I was looking around and I'm think I'm going to put it into a frame of an Swedish company that has a size of 50 by 50cm, I guess it should fit. It is also a rather bulky frame, so I hope I can fit the pi and the buttons into it.

Tomorrow I will grab on of the PIs I have and look the local shop of this Swedish company.

As I see it at the moment I have to create the stencil with the python program and get it done as written above a company like ponoko and put it onto the glass or in between.

In the video and the pictures of the guide you use a rather thick wood, I guess I can also use a thinner one, or was it on purpose to get a better lighting of the characters?

Sorry to ask so many stupid questions but better to ask before starting than doing it once over again.

Regards
Pinz

bk1285, 2016-08-01:
Hi @i-pinz,

your concept with the frame of the swedish company sounds interesting! ;) Since it's a somehow new approach (compared to mine), it would be great, if you'd share a picture or two of the final result... :)

The thick wood improved indeed the illumination of the characters (ensuring a minimum distance between LED and plate).

Good luck and best regards,
Bernd

bk1285, 2016-08-01:
PS: If you rerun the python scripts with your own measures of the stancil, consider the correct spacing of the characters according to the LED-strip you use. If you choose the spacing to wide, your LED-strip might not be useable anymore... ;)

stefancarlton, 2016-08-01:
Hi pinz,

I did something similar with a wooden frame (albeit custom made) and you
can see the steps I took here http://clock.stefancarlton.net

One thing i learned is the importance of the diffuser material, the
distance between the led & the diffuser and the size of the letter cutouts.
The one i built is a bit glarey and doesn't glow like Bernd's does.

Remember as well you can get led strips with 60per metre so you can make
the clock much more dense.

Stefan

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

Tetrikus, 2016-08-02:
Hi all
I actually used the glass front of the Swedish wooden frame but have built a wood/alu frame around it since I felt like the frame is too deep. I reduced the depht of the clock to about 3cm and I guess the Ribba frame was a bit more.
Looks quite nice in my opinion but I will build a few more clock faces out of plexiglas in different colors and glue some magnets on it to make it easily replacable.

If you are interested in details and pictures:
_http://tetrikus.com/projects/portfolio/homemade-wordclock/_

But I also learned, that it's not a good idea to connect the strips one after another. After a few months of running fine, the clock broke and almost all of my LED strips where gone. I will now rebuild the clock from scratch and improve the power supply.

HeerNMeester, 2017-08-13:
I finished mine a few months ago but haven't shared my details.
I have 2 front panels. An brushed aluminium and a Corten Steel one, which I let a few weeks outside to rust. I got them from Geers Cutting in Germany. (thickness 1 mm) You do have to provide them with the correct files. I tried to convert the .eps file from the stencil creator but that is not converted correctly by all programs I have tried. Eventually I manually adapted them in a CAD program. Not to difficult, but not straight forward.
As for the font. Since it's laser cut, you need to have a special font that keeps the inside of some letters intact (A,O,R etc). I couldn't find a stencil font to my liking. I ended up adapting DIN regular with a font creator.
Oh tip: as a diffuser layer I used some greaseproof paper (the type you use in the oven to bake).

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

bk1285, 2017-08-31:
Woohoo! Looks great, @HeerNMeester !!

ruedli, 2017-12-22:
I noticed the STL files in the template directory and now I got a 3D printer (multi material) I was inspired to try this and take it a step further.

To summarize:
I now use three different! templates with transparent, printed characters. I can shift between them with servo's and show "english" or "dutch" or "round dots". When no frame is used, you see 16x33 mm lighted rectangles, great for playing Tetris! The diffusers are printed as well: one layer of white (0.15mm) between transparant (2x 0.8mm on a stand).

The leds shine through transparent templates, everything is printed and the frames can slide.

I have finished the printed parts of the frame, remaining to do: hook up the pi, update the software to operate the 12 servo's, using a PCA9585, use mij wiring, use my dutch template with support for expessions for the minutes (het is zo / het is bijna / het was / het is nu / het is na / )

Enough to do therefore. I am willing to share my .stl files, they were made in fusion 360 from scratch.

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

bk1285, 2017-12-22:
Hi @ruedli,

looks great, excellent work! Easiest way to integrate the stl is to create a pull request to "develop", which I can merge afterwards.

Best,
Bernd

ruedli, 2017-12-22:
There is quite something to it, to reprint it you need over 400 .stl files. Many of them need to be sliced at the same time, because they come from "multi material"  model and need to be sliced in the proper position. The "B" for instance is a shape in the (black) template, filled with a transparent "B" and on top of the transparent "B" the inner two parts are modelled in black again. So... The character "B" is made of 3 bodies, not just one, as e.g. the character "T". In "Slic3r PE" this is a matter of drag / drop all .stl files that belong together in one go, then slice and print. This is needed for the templates (the 3 that I  prepared come as 4 quarter parts each, due to max size of my printer (205mm x 250mm) and the diffuser (this diffuser needs to be printed 110 times: one for each character position)

An interested maker would probably need more slicer instructions, we will see. For now I attach all needed .stl files here with this post, with a "view" on these files in fusion 360.

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

I will tune them further and when I am done create the "pull request" mentioned by Bernd. I also need to figure out how to update the software so that multiple (servo operated) templates can be configured without breaking it for the normal one template only.... check that the PI can do the 12 servo's through I2C and PCA9685 and need to study how software update is best done, suggestions are more than welcome here!

Needless to say I am willing to help anyone courageous enough to try the same! In that case I will write more detailed instructions. So, if someone is interested in printing this 3D clock (it easily fits in the well known IKEA frame) let me know.

I have printed mine on my Prusa i3 MKs2 Multi Material.

Have fun,
ruud
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
bk1285, 2017-12-22:
Hi @ruedli,

nice! Short video to see the clock in action is highly welcome!! ;)

Best,
Bernd

ruedli, 2017-12-22:
Yes, will do that when the servo's are working and when I got the software
all in one piece ;-)

2017-12-22 18:19 GMT+01:00 Bernd Krolla <notifications@github.com>:

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

--
Ruud Rademaker
prefered mail: ruud.rademaker@gmail.com

ruedli, 2017-12-27:
I have created my own wiring sceme updating wiring.py, since I had glued my LED strips running n opposite direction. It now works and after small updates to reflect my specific templates the time displays correctly and and the plugins work.

I have the following questions: the numbers that are shown in the images of the of the "wordclock_layouts" (linke the wiring_front_bernds_wiring.pngand wiring_front_bernds_wiring.svg files) seem to be based on a horizontal strip arrangement, they do not correspond to the strip index and do not start e.g. with a "LED 0", what are they?

Can the stencil files and layout files be generated somehow or are they manually created/edited?

Is it meaningful to publish/provide updates to the stencils and wiring with the corresponding software updates? I have e.g. created an "english2" wiring and corresponding needed update in a (new) file called "time_english2.py" with provisioning line in "show_time" of the "plugin.py" of the time_default plugin, etc..

ruedli, 2018-01-02:
So... ITS WORKING... yesss, so pleased with the result...

Here is the video: https://youtu.be/XTHH30S8Aao

I have created a new "issue" to assist with merging the new plugin in the framework. I built in the support for servo switching in the existing classes for setting the time, this was needed to allow the core time software of the clock to switch between languages.

The change was done very cleanly, with hardly any impact to the existing classes. It now uses a list of classes for each language (and only the relevant ones) that needs to be support, rather then only one loaded class.

This was done by support for reading a comma separated list of languages, rather then "only one" language. A new plugin can be used to set the "active_stencil". The servos are configured in there own configuration section called "servos".

aupp, 2023-08-12:
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

A long time since you did this, but would it be possible to share the font yiu created? If you still have it? 😊
The clocks looks awesome btw! How did the rusty corten one end up?

ruedli, 2023-08-13:
Well.... because I 3D printed it from plastic, I printed the characters from transparent plastic in the black plastic that surrounded the characters. For the diffuser layer I used one layer of white filament :-)

The font is plain old Arial

HeerNMeester, 2023-08-13:
@ruedli I think he is asking for my font ;-)
@aupp I just made a pull request with the stencil font I made. Luckily I had it somewhere on an old cloud account...
I prefer the brushed RVS over the Corten steel plate. It turned out quitte good, but it doesn't fit in our livingroom. I did made a few other ones, like this one in Bamboo. Letters are lasercut, but because of the thickness of the plate (5mm) the view from an angle is bad (you are looking into the sides of the letters and the light is not coming trough. So I filled them with an epoxy resin with a diffuser additive. The pouring was easy, only the sanding afterwards was quite a job!
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

ruedli, 2023-08-13:
Ja, denk ik ook :-)

Op zo 13 aug 2023 om 18:00 schreef HeerNMeester ***@***.***>:

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

--
Ruud Rademaker
prefered mail: ***@***.***

ruedli, 2023-08-13:
If you fill it up with resin, you can temporarily glue "loose" centre parts
of characters to a flat surface together with the stencil and then pour the
resin. Anyone tried that?

Op zo 13 aug 2023 om 18:00 schreef HeerNMeester ***@***.***>:

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

--
Ruud Rademaker
prefered mail: ***@***.***

aupp, 2023-08-13:
Yes, you're right, the DIN-font was what I was hoping for. Very nice
😊Thanks!

The bamboo looks really cool too! 👍

sön 13 aug. 2023 kl. 18:00 skrev HeerNMeester ***@***.***>:

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
--
Med vänliga hälsningar
Andreas

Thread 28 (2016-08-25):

not functioning correctly

ELViTO12, 2016-08-25:
Hello,
I have some troubles getting the clock to work. I connected all the cables to my rpi2b following bernds wiring and with the test function of the rpi_ws281x package i tested all the leds and they work. However when i start the rpi_wordclock all the leds randomly start flashing but it does not show the time. I installed raspbian and all of the packages twice and allso changed the rpi_ws281x library to  'Richards' library but that didnt work so i changed back to the 'original' jgarff library. Any ideas what i can change next?  Is there a way to start the plugins from the terminal  because i also dont understand what the buttons do. Thank you for your help!

tooliload, 2016-08-25:
Hi have you setup the right wirering in settings? What wirering layout use you?

ELViTO12, 2016-08-25:
I am using bernds wiring which is also default in the wordclock config so i did not have to change that.
I saw in the specifications of rpi_ws281x : 'Converting the output from a Raspberry Pi GPIO/PWM to a higher voltage through a level shifter is required.'  I however did not see it in the layout of the tutorial nor in the video of the wiring so i also didnt do it,or maybe i missed it. Maybe that is my error?

bk1285, 2016-08-28:
Hi @ELViTO12,
thanks for reporting. That's very strange! Sebastian, a friend of me, ran into the very same problem few days ago.

First, I thought about blacklisting the audio-kernel (as described here https://github.com/jgarff/rpi_ws281x/commit/27229b24028082b2ef9314c6247f621af296486d )
But since the LEDs work with the rpi_ws281x-package, this should not be the point.

I'll meet with Sebastian throughout this week to investigate. I'll keep you updated! :)

Regards,
Bernd

bk1285, 2016-08-29:
Hi @ELViTO12,

in our case, it's about blacklisting the audio-kernel... Can you check this: http://www.instructables.com/id/Disable-the-Built-in-Sound-Card-of-Raspberry-Pi/ and confirm? If this resolves your issue as well, I'll add it to the docs. Please confirm.

Regards,
Bernd

ELViTO12, 2016-08-29:
Hi Bernd,

Thank you very much for responding and finding a possible solution! I will follow the steps of the tutorial this week and will keep you posted.

Regards

ELViTO12, 2016-08-30:
I just implemented the solution and it works like a charm! Thank you very much for your advice :smile:
 I also wanted to note that I have installed the rpi_ws281x package of jgarff on my raspberry pi 2 and it works. The recommended "Richards library" does not work.

bk1285, 2016-09-10:
@ELViTO12 @tooliload

thanks for your reports/advices. I updated the docs accordingly: https://github.com/bk1285/rpi_wordclock/commit/cb47c9d8fd06cefb08efb13101c305efcdc691e7

Regards! :)

Closed 2016-09-10.

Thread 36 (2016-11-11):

"am2303_rpi" no longer available in pip repository

oxivanisher, 2016-11-11:
It seems as the " am2303_rpi" is no longer available in the pip repository. I did not find another way to get the temperature and humidity sensor working.

bk1285, 2016-11-14:
How about this: https://learn.adafruit.com/dht-humidity-sensing-on-raspberry-pi-with-gdocs-logging/software-install-updated

Would be great to have short feedback, if and how it works...

Regards,
Bernd

oxivanisher, 2016-11-14:
I did all that already, but the rpi_wordclock still prints:
```
Imported plugin 5: "restart".
  Assumes no temperature sensor to be attached.
```
But, the tests from the Adafruit site are working.
```
root@wordclock:/home/pi/Adafruit_Python_DHT/examples# ./AdafruitDHT.py 2302 4
Temp=20.0*  Humidity=42.4%
```

bk1285, 2016-12-01:
Can you check with am2302 (instead of am2303)? To me, the docs seem to be a bit inconsistent here? http://rpi-wordclock.readthedocs.io/en/latest/doc_software_setup.html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

oxivanisher, 2016-12-23:
I was very busy the last weeks, but I will have a look at this the next week :+1:

bk1285, 2017-01-02:
Hey @oxivanisher

Found the dependency to be wrong...
Fix is here: f4bbcfebc22b9185c9de7d1502e8837ff00c5580

Please reopen, if the issue persists.

Closed 2017-01-02.

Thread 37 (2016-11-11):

NeoPixel dependency is too old to accept customized brightness values and correct RGB-settings

oxivanisher, 2016-11-11:
I did a clean install of the wordclock software as documented in the readme. With the current master of the https://github.com/jgarff/rpi_ws281x library, the wordlock is not working And with the mentioned commit https://github.com/jgarff/rpi_ws281x/tree/2f9e03c45ba0964029204db565ad9d6233b3a1a6, I get the following warning:
```
Exception AttributeError: "'Adafruit_NeoPixel' object has no attribute '_leds'" in <bound method Adafruit_NeoPixel.__del__ of <neopixel.Adafruit_NeoPixel object at 0xb633f370>> ignored
WARNING: Your NeoPixel dependency is to old to accept customized brightness values and correct RGB-settings.
```
Do you have another commit with these features available which you know that it is running?

bk1285, 2016-11-14:
Hi @oxivanisher,
do you have any further details, why the clock doesn't work with the current master from rpi_ws281x?
Regards,
Bernd

oxivanisher, 2016-11-15:
Yes, the error is the following:
```
root@wordclock:~# python /home/pi/rpi_wordclock/wordclock.py
Parsing /home/pi/rpi_wordclock/wordclock_config/wordclock_config.cfg
Setting up wordclock interface
Interface type set to gpio_low (False)
  Mapping button "left" to pin 17.
  Mapping button "return" to pin 22.
  Mapping button "right" to pin 24.
  Lock time of buttons is 0.2 seconds
Wiring configuration
  WCA_WIDTH: 11
  WCA_HEIGHT: 10
  Num of LEDs: 114
Traceback (most recent call last):
  File "/home/pi/rpi_wordclock/wordclock.py", line 144, in <module>
    word_clock = wordclock()
  File "/home/pi/rpi_wordclock/wordclock.py", line 41, in __init__
    self.wcd = wcd.wordclock_display(self.config)
  File "/home/pi/rpi_wordclock/wordclock_tools/wordclock_display.py", line 35, in __init__
    self.strip.begin()
  File "build/bdist.linux-armv6l/egg/neopixel.py", line 113, in begin
AttributeError: 'module' object has no attribute 'WS2811_SUCCESS'
```
I tried hacking around for some minutes, but since I have other problems with the project, I did not investigate it deeper at the moment. 😁

bk1285, 2016-11-18:
Just merged your pull request back. Great work, @oxivanisher I especially like the 3d printing part...!

bk1285, 2016-12-18:
Hi @oxivanisher, I recently setup another wordclock, but did not run into this issue.... Did you make you clock run meanwhile?

Regards,
Bernd

bk1285, 2016-12-21:
Please reooen, if the issue still exists.

Closed 2016-12-21.

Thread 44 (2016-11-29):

Raspberry Pi Zero

Nthl25, 2016-11-29:
Hallo,

kann mir jemand von euch sagen, ob die Wordclock auch mit einem Raspberry Pi Zero funktioniert?
Leider gibt's häufig nur noch den Pi 3 zu kaufen, der ist aber in meinen Augen völlig überdimensioniert.

Grüße
nthl25

bk1285, 2016-11-30:
Bin kurz davor das zu testen... Werde mich mit Updates melden.

Regarding the RPi3: Agreed, this one is overdimensioned. RPi0 would be great... ;)

HeerNMeester, 2016-11-30:
I'm building a version based on the RPi0. A Dutch 11x10 to be precise. So far I have installed the software, which gave no problem (except the AM2302 temperature sensor, but that a known issue). I don't expect further problems. My time is limited, so progress is slow.

Nthl25, 2016-12-01:
Hallo zusammen,

ich bekomme beim installieren von python-scipy auf meinem Pi0 folgenden Fehler:

Es wurden 25,6 MB in 2 min 55 s geholt (145 kB/s).
E: Fehlschlag beim Holen von http://mirrordirector.raspbian.org/raspbian/pool/main/p/pillow/python-imaging_2.6.1-2+deb8u2_all.deb  404  Not Found [IP: 5.153.225.207 80].

Habt ihr eine Idee, was ich da machen kann?

Grüße

bk1285, 2016-12-01:
@Nthl25 , Moved your issue here https://github.com/bk1285/rpi_wordclock/issues/45 since its not related to the Pi0

Nthl25, 2016-12-02:
@bk1285 , okay. First I thought it was a RPi0-Problem. So I postet it in this issue. Hope anyone can help :)

HeerNMeester, 2016-12-11:
Yesterday I started my word clock with RPi0 for the first time. It it still a bread board design, but it worked fine (Many thanx to @bk1285 !!).
Only a few issues which can be resolved, but are not related to the use of the RPi0. (I also use a cheap China LED strip, so my colors are inverted as well (need to update the software) and my clock seems to be running one hour behind (daylight saving time??).)
Temperature and light sensor need to be implemented still. I do not use a level shifter at the moment.

bk1285, 2016-12-12:
Hi @HeerNMeester thanks for the feedback! I had the software running on a RPi0 as well (without attaching the actual LEDs). So I close this issue and add a note to the docs concerning the compatibility with the RPi0.

Closed 2016-12-12.

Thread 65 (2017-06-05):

rasperry pi zero not compatible ?

Carlos464, 2017-06-05:
Hello,

I am trying to get the wordclock up and running with an raspberry pi zero, but that does not work. The software is running, but none of the LEDs is getting on.

The same config with an rpi2 is running fine.

Do I have to tweak the software?
Anyone else having these issues?

Thanks in advance.

Carlos

adamenatsky, 2017-06-10:
Hi Carlos. I have gotten the clock to start working on a pi zero w. A few possible bugs I noticed after tinkering are that I had to disable the opening message in the config file for the clock to start working, not sure why. Second issue I ran into was that the clock would only work when started from the cron at boot. When starting it manually from the command line the lights would just blink randomly and show me a jumble of colors. Otherwise it works fantastically on the pi zero. Let me know if I can help with any questions you have. I'm not an expert just a hobbyist by the way.

Carlos464, 2017-06-12:
Hi adamenatsky,

thanks for your reply.

Do you use the same GPIO Pins as mentioned in the docs?
The opening message is already deactivated and the program starts via cron at boot.

best regards
Carlos

adamenatsky, 2017-06-12:
Yes I followed Bernd's wiring and GPIO pin usage. My python skills are quite novice so I didn't want to mess around with the source code until I got comfortable with the device working in its normal state.

bk1285, 2017-06-14:
Hi all, thanks for your input!

Find first reports and discussions on Pi0 here:
https://github.com/bk1285/rpi_wordclock/issues/44
Hope it helps you make the clock run.

Just in case you find out futher tricks, it's great, if you share them here.

Best,
Bernd

bk1285, 2017-06-14:
Did you take this page into consideration: https://github.com/bk1285/rpi_wordclock/blob/master/docs/doc_troubleshooting.rst

... a disabled soundcard for only one of the two Pis might be an issue?

adamenatsky, 2017-06-14:
Hey Bernd I'm new this whole github community. Should I add any notes I posted here to he #44? Or is the link you put up good enough?

And yes I did look at the troubleshooting page early on. Only issue I ran into listed there was the GPIO Pin 17 thing. But that was cleared up quickly once I connected the buttons and LEDs.

Thanks for your all you work on this project! Its been fun getting it up and running.

Carlos464, 2017-06-14:
Hi Bernd.
I just tried the suggestions from your link.
Still no luck.

Anyone any ideas?

best regards
Carlos

Carlos464, 2017-06-16:
@adamenatsky

Can you do me a favor and post the output of

`gpio readall`

on your working raspberry pi zero.

Thanks in advance.

best regards
Carlos

adamenatsky, 2017-06-19:
@Carlos464 I will do so hopefully later this evening or tomorrow. I'm just now resoldering my buttons  in a permanant placement and will have the pi up and running then.

Carlos464, 2017-07-01:
Hi all,

it's still not working with the rPi0.
Would love to get it up and running.

@adamenatsky
Any chance to upload a screen of the output of

`gpio readall`

best regards
Carlos

adamenatsky, 2017-07-05:
@Carlos464 Apologies for the delay. As I'm not good at soldering, I damaged some of the pixel connections while making permanent wiring placements and I am in the process of redoing them. I'll get your readall as soon as I can.

Carlos464, 2017-07-10:
@adamenatsky

I started over from scratch and now it is working with the raspberry pi zero.
From smoke to smother. Now the rPi hangs randomly.
I will open a new thread.

best regards
Carlos

ruedli, 2017-12-27:
I installed jessi-lite (2017-11-29-raspbian-stretch-lite) on a "raspberry pi zero w" and found the clock would not compile, complaining about missing modules: freetype and monotic.

It showed:
Traceback (most recent call last):
  File "wordclock.py", line 8, in <module>
    import wordclock_tools.wordclock_display as wcd
  File "/home/pi/rpi_wordclock/wordclock_tools/wordclock_display.py", line 1, in <module>
    import fontdemo
  File "/home/pi/rpi_wordclock/wordclock_tools/fontdemo.py", line 30, in <module>
    import freetype

and

Traceback (most recent call last):
  File "wordclock.py", line 9, in <module>
    import wordclock_tools.wordclock_socket as wcs
  File "/home/pi/rpi_wordclock/wordclock_tools/wordclock_socket.py", line 5, in <module>
    from wordclock_interfaces.event_handler import event_handler as eh
  File "/home/pi/rpi_wordclock/wordclock_interfaces/event_handler.py", line 3, in <module>
    from monotonic import monotonic as _time
ImportError: No module named monotonic

The resolution for me was (sorry, if this should have be done easier, I am new to raspberry and python):

cd ~
git clone https://github.com/rougier/freetype-py.git
git clone https://github.com/atdt/monotonic.git

cd ~\freetype-py
sudo python setup.py build
sudo python setup.py install

cd ~\monotonic
sudo python setup.py build
sudo python setup.py install

after installing you can remove the cloned monotonic and freetype installation directories.

Also, an installation step to set your current timezone and DST was missing, which can be done using sudo raspi-config in the localization option.

Closed 2018-01-04.

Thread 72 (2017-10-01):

Power supply

DavaD85, 2017-10-01:
Hi
I'm planning to buy the power supply for led strip and raspberry pi III, do you have idea about sizing? Di you have an example of power supply I need? Thanks

bk1285, 2017-10-01:
Hi @DavaD85,

here we go:
http://astore.amazon.de/araspbepibase-21/detail/B00KETLBAU

http://astore.amazon.de/araspbepibase-21

Best regards,
Bernd

DavaD85, 2017-10-01:
Great!! Thanks a lot I'll buy it and start soldering everything.

DavaD85, 2017-10-01:
Docooler AC 100V ~ 240V a DC 5V 12A 60W Tensione Trasformatore Interruttore Alimentazione per Striscia LED https://www.amazon.it/dp/B01M0VFYUT/ref=cm_sw_r_cp_apa_mZq0zbFK46MB7

Can be this ok? I've the power not near the clock and with this I can attach a long cable, 60w 12a 5v

bk1285, 2017-10-01:
Should be fine... :) Already with 10A, you can continuously run all 114 LEDs at full brightness. To show the current time, you need around 20-25 of them. Only some plugins require more LEDs (Tetris, etc...)

Best,
Bernd

DavaD85, 2017-10-01:
Ok so finally I bought this

https://www.amazon.de/gp/aw/d/B00MWQF6M2/ref=mp_s_a_1_1?__mk_de_DE=ÅMÅZÕÑ&qid=1506874273&sr=8-1&pi=AC_SX236_SY340_FMwebp_QL65&keywords=lpv+100+5&dpPl=1&dpID=3167vJ9lKqL&ref=plSrch

I've to put it in a small box in the wall, I think this is perfect :)

ruedli, 2017-10-07:
I did not like the rather high current of the 5V supply.... So considering another approach: I will use "an old" 23V notebook adapter and use 5 stepdown convertors for the matrix and one for the PI.

So: then (if I use 90% efficiency, they even claim 97.5% but I do not believe that) the max current for all leds on in the matrix from the notebook power supply is **less than 2A.** I will try and use these:

https://www.aliexpress.com/item/Mini-DC-DC-12-24V-To-5V-3A-Step-Down-Power-Supply-Module-Buck-Converter-Adjustable/32767397427.html

It should be much better in terms of voltage loss over the supply lines. If you hook up a 5V PSU directly, due to the large current, the voltage at the strips will be significantly less than 5V. With the step down convertors right next to the strips this is no longer the issue AND the step down convertors will happily take any voltage input as long as it is higher than 6V and convert it to exactly 5V. This will never be an issue with the 23V input and the lower current.

So far the theory.... I've only used this with Arduinos and around 500 animated LEDS in a matrix (not pixels, I used 4 HT16K32 drivers for 128 LEDS each) in my pinball machine. That worked great. I will keep you posted. If someone thinks this is a **bad idea for** the clock for things I have overlooked: **please comment.**

bk1285, 2017-10-21:
Hi @ruedli,
meanwhile, a huge amount of people built the raspberry-based wordclock, using the power supply, as proposed in the documentation of this project. Since I'm not an expert in electronic, I cannot comment on your plans in any way.

Regards,
Bernd

ruedli, 2017-10-21:
Hi Bernd,

Thanks for looking into it, I can understand your point. For that matter: I
am an electronic engineer, but the clock doesn't know that ;-)
I'll give it a try and see if it flies.

Regards,

Ruud

2017-10-21 16:10 GMT+02:00 Bernd Krolla <notifications@github.com>:

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

--
Ruud Rademaker
prefered mail: ruud.rademaker@gmail.com

ruedli, 2017-12-27:
So, the clock is running for two days on the mentioned small step-down convertors (less then 50 cents each).

I am now using 4: one for the pi and three for the strips. The strip ones serve each a separate part of the matrix:

- convertor 1 left 3x10 LEDS + the left minutes LED, so 32 LEDS in total.
- convertor 2 middle 4x10 LEDS, so 40 LEDS in total.
- convertor 3 right 3x10 LEDS + the right minutes LED, so 32 LEDS in total.

Each convertor delivers 5V and 3A max, can be supplied by anything DC from 7V to 29V (I am using an old DELL notebook adapter providing 19.5V). You need the same mount of Watts as specified for the clock, but now the needed current will be lower because of the higher voltage.

https://www.aliexpress.com/item/5V-3A-Mini-Step-Down-Power-Supply-Module-DC-DC-Converter-Input-7V-28V-Output/32825744436.html

In this way the voltage suppllied at the strip and RPI is indeed 5V, less loss over the line, wince the current provided by the PSU is lower and is regulated to be precisely 5V (in fact mine are between 4.96V and 5.10V).

I will add small cooling sinks, but even when all the LEDS are "full whites", for many hours, these step down convertors get "warm", but not too much. At the normal clock display mode, they do not even get warm.

I will add two additional 6V drivers for my 12 servo's...

As Bernd mentioned, I provide the information as-is, without guarantees for success, however, from an electrical engineering perspective this solution made sense to me, which is why I provide this feedback.

Closed 2018-01-04.

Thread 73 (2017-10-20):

Clock is stable for a while, but after a week or so....

Arjan444, 2017-10-20:
Dear All, I have a strange phenomenon. My Clock is completely build as described in this repository including level shifter, lots of extra VCC and GND wires to make sure there is enough grounding and voltage distributed over all LED stripes, 5V/10 Amp power source, resistor before the data hits the first led. Everything works like a charm, but then after a week or so I see strange colours appear and random LEDs turn on. Switching the power off/on helps for a while but after a day or so the same problems reoccurs.

Is it the Pi? Is it the level shifter? Could it be the Leds? I'm puzzled. Looks to me like a fuzzy problem (everything works for multiple days and then all of a sudden I see strange led behaviour).

Please help with a sensible, logical explanation.

Thanks! Arjan

bk1285, 2017-10-21:
Hi @Arjan444,
indeed, that's a strange thing. You're the first to report this kind of issue and I suspect the hardware causing this behavior. I currently don't have any idea, what could be the reason for this...
But feel free to upload some pictures of your wiring here, to get the discussion started.

Regards,
Bernd

mrksngl, 2017-10-21:
I've seen similar things in another project, and it turned out to be a problem of the clock (but in that project I have a really fast update, i.e. clock speeds at the very upper limit of the strip) and especially the level shifter (one of them was too slow, the other one too weak). It should also be noted, that the strip I used had seperate clock and data wires, which can also introduce some more trouble.

I would recommend to first check your soldering points again. And you should make sure there is litte cross talk on the wire (i.e. do not make the data/clock wire longer than needed -- especially: do not loop it).

Which level shifter did you use? I don't really get "resistor before first led", can you tell me more about you wiring? Or could you provide a link to the document/issue describing your setup?

It could also be an issue of your power supply which could either be too weak or at least too unstable. You could try to add a capacitor (e.g. 4.7uF) right before the led strip begins.

Is your problem affecting all LEDs or only some of later points in the LED chain, i.e. assuming you used bernd's wiring, is the error occuring at all rows or some later rows?

Regards,
mrks

Arjan444, 2017-10-21:
Thank you mrks. The strip I use, uses separate clock and data wires. I think you confirm my suspicion that it had something to with the wiring. I use clips to connect the strips, and since they are  15 cm I have to curl/loop them a bit. And that may influence the clock signal.

For a level shifter I used the 74AHCT125 . With 'resistor before the Leds' I mean I a 470 Ohm resistor between the level shifter and the first Led. I haven't tried a capacitor before the Leds, but I don't think the power supply is the problem.

The problem occurs all over the matrix, so it is not limited to certain columns. However, the later rows are surely more affected more than the first. I do use Bernd's wiring.

I think I have to rewire everything. I'll use Neopixels (3 separate clock/data) instead, and no clips.

Thanks a lot. Regads, Arjan

bk1285, 2018-01-18:
@Arjan444
if the issue reappears, feel free to reopen at any time.

Arjan444, 2018-01-18:
Thanks Bernd. Stable since I replaced the leds with Neopixels.

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

Closed 2018-01-18.

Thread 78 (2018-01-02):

Support for multiple stencils, operated by servos

ruedli, 2018-01-02:
My clock has three moveable stencils, that can be moved with servo's.

All is working now, and I have created a plugin to allow for choosing the template to use for time_default, sunrise and matrix_time.

You need to install and enable i2c support and import the ADAfruit_PCA9685 module.

I have:
- Added my wiring
- Added a stencil "dutch2"
- Added a stencil "english2"
- Added a plugin "stencil_changer"
- updated the configuration file to allow configuring the servos to use and their settings for activating the different stencils
- updated "woordclock.display.py", so that it can also be used for changing stencils in other plugins.
- updated the sunrise plugin, so that it uses "dots" for animation and the correct (selectable) template for showing the time for sunrise/sunset.
- moved the time_xxxxx.py files from the time_default plugin to the wordclock_tools directory and made the selection of the correct time translation generic: until now every plugion had to use their own selection of time_xxxx modules, and they were not up-to-date, nor complete.

The code and configuration files contain explanation and examples.

I have tested, that this also works "without" the new hardware for the servo's, so it does not break the functionality for clocks without servos.

I have everything versioned in git, but have trouble committing this delta (I do not see "files" on a branch to commit to), so for now enclose the "unified diff" as pdf.

[unfied diff Ruud Rademaker inplementation of servo changer.pdf]
(https://github.com/bk1285/rpi_wordclock/files/1597659/unfied.diff.Ruud.Rademaker.inplementation.of.servo.changer.pdf)

as well as the modified / moved files.

[rpi_wordclock.zip](https://github.com/bk1285/rpi_wordclock/files/1597674/rpi_wordclock.zip)

Please let me know how I can contribute it into the repository, and what to do next. Will try to upload a video as well with this new "feature" all people that have seen it so far, were very impressed... And, obviously the clock pleases me as well. (Perhaps exchange by mail further info, that would be much more efficient)

Thnx Bernd for creating the excellent starting conditions for having this feature!!!! As I implemented these changes, I got very impressed with the nice framework you have created, software!

ruedli, 2018-01-02:
And... here is the video....

https://youtu.be/XTHH30S8Aao

With some pictures of the mechnism, Software, with a new plugin, is now fully functional, I intend to build a second row of 3 servos to the right, currently I only use 3 servos, one for each stencil.

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

This picture shows the driver for the up to 16 servos, a 2 dollar TDA-9685 breakout. (Uses i2c and does all timing stuff, without bothering the raspberry pi)

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

bk1285, 2018-01-03:
Hi @ruedli, really nice clock! Thanks for sharing!!

....definitely a strong candidate for the gallery (...to come...)

ruedli, 2018-01-04:
Hi Bernd,

As mentioned, I have the code managed under git here on my PC, how do you
want to proceed now?

Leave it on my PC only?
-or-
Review the changes and merge it with your code repository?

I set it up in such a manner, that it does not break the functions for
people not having servos to operate the stencils. At the same time, people
who swap their stencil manually, with magnets e.g. could benefit from the
"stencil changer" plugin.

There are new dependencies however: for i2c and the Adafruit library, they
must be included in the software installation doc.

You can mail me to my private mail, to exchange ideas on the merge, also I
could program other new feature, I intend a few more addons myself.

cheers Ruud

(ps. I also resolved a "bug" when you configure the initial brightness
level at a vaule larger then 247, it crashes the clock in an attempt to set
the intensity at values bigger then 255, the "check" for bigger then 255
was at the wrong place, and the "change direction logic not working
properly)

2018-01-03 12:09 GMT+01:00 Bernd Krolla <notifications@github.com>:

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

--
Ruud Rademaker
prefered mail: ruud.rademaker@gmail.com

bk1285, 2018-01-04:
Hi @ruedli,

please create a [pull request](https://help.github.com/articles/about-pull-requests/) to "develop".

Then we can discuss changes in detail and decide, whether to integrate the soures (and documentation) into develop (preferred!) or leave it on a separate branch.

Best,
Bernd

ruedli, 2018-01-04:
Hi Bernd,

Sorry I feel like an idiot, but despite more then 15 years experience
selling configuration management solutions, I do not succeed in uploading
the delta's to the files...

When I create the pull request and "drag-and-drop'.py files, I get a file
type not supported. I never see a directory tree, where I would expect to
be able to upload individual files.

Finally, I did not base my development on "develop",  but on the master
copy of a week ago. The develop already contains a change. Even if you
already migrated it, adding my change there should create either a conflict
or undo the intended change currectly in the development branch. (If I
understand correctly how this is supposed to work...

So please, a little help on making the pull request work for us, so that I
can update and add .py files and that we use the correct baseline for the
pull request...

(sorry for not understanding)

2018-01-04 12:06 GMT+01:00 Bernd Krolla <notifications@github.com>:

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

--
Ruud Rademaker
prefered mail: ruud.rademaker@gmail.com

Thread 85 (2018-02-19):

DMA 5 Problem with SD Card on Pi Zero and Pi3

thejoe8495, 2018-02-19:
There is an SDCard issue on the new Pis. The DMA5 is used to access the SDCard when you start the Wordclock the pi will eject the SD Card and crash.
Please change
https://github.com/bk1285/rpi_wordclock/blob/f61f8f3c674cd7c9393905a19ed8d397ecd7ca9d/wordclock_tools/wiring.py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
to DMA 10

For more information:
https://github.com/jgarff/rpi_ws281x/issues/188

bk1285, 2018-02-19:
Hi @thejoe8495
excellent! Thanks for reporting! I already ran into the issue, but wasn't able to track it down...
Best,
Bernd

bk1285, 2018-02-19:
@thejoe8495 can you provide feedback, if it works with the latest master?

thejoe8495, 2018-02-19:
Yes it work on my pi zero, for the pi3 i need to wait my octopi finished with printing :wink:

bk1285, 2018-02-24:
Please reopen, in case it does not work with the Pi3.

Best,
Bernd

Closed 2018-02-24.

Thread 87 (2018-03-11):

Wordclock lost the 11 letters

pizzajt, 2018-03-11:
First: Many thanks to the Great work and a wonderful wordclock!

It Looks great.

Since the last days my wordclock lost the last 11 letters and the last 2 dots in the Strippe.

So the word „ES“ is missing.
I used Strandtest, it stops after „GRE“

The clock worked Fine the last year an I didn‘t change anything.

pizzajt, 2018-03-11:
https://photos.app.goo.gl/nZc4WdQaYKL7z3ah2

bk1285, 2018-03-11:
Hey @pizzajt,
I'd guess, it's a hardware issue: Check the soldering at the point, where the 11 letters "get lost".
Possibly, you have to renew the solderimg or replace some defect LEDs at that point.

Best,
Bernd

pizzajt, 2018-03-11:
Hi Bernd.

Are you shure this will be a hardware issue?

At this Point there is no soldering, i use 1 strip per coloumn.

So i have to cut the strip and will change the led „S“.

Many thanks!

pizzajt, 2018-03-11:
I changed the LED - everything is working fine!
Here you can find some pictures of my „making of“:

https://photos.app.goo.gl/oGf6EfMomIlovqdL2

pizzajt, 2018-03-11:
I ordered the Front Panel at

LTO GmbH
eMail: info@lto-gmbh.de

Frontplatte
Typ: DXF-Import
Material: Stahl DC01
Materialdicke: 1mm
Oberfläche: matt
Datei: wiring_front_JT7.dxf
Interne Datei: dxf_57e11e69d6308.dxf

23,94 €

bk1285, 2018-03-11:
Great, good to know!
...and thanks for the feedback. I'll add the images to the wordclock gallery on pinterest, if you don't mind... ;)

Closed 2018-03-11.

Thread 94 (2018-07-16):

Buttons

crob11, 2018-07-16:
Hallo Bernd,

ich habe die Wordclock nach Anleitung gebaut inkl. den 3 Buttons. Auch der Autostart wurde eingepflegt. Den Code habe ich nicht verändert.

Zum Problem:
Die Buttons hatten beim ersten Start sogar mal funktioniert (konnte verschiedene Farben wechseln etc.). Nach Trennen der Stromzufuhr und wiederverbinden funktionieren die Buttons nicht mehr (keine Funktion) und die Wordclock arbeitet stets auf einer Farbe. Die Verschaltung habe ich mehrfach überprüft und keinen Fehler gefunden (habe auch nix verändert).

Wo liegt mein Fehler? Für jegliche Ideen/Hilfe vielen Dank im Voraus!

schweizschweiz, 2018-07-26:
Auch mit einem Multimeter gemessen?

crob11, 2018-07-28:
Falls du die Spannung über den Button meinst,... ja.
An den Buttons liegen jeweils 3,3V an (kommt ja ausm GPIO und müsste passen)

schweizschweiz, 2018-08-01:
Und die Spannung fällt auch auf 0v wenn du einen gedrückt hältst? Also es klingt ja eher nach Hardware als Software Fehler oder nicht?

bk1285, 2018-09-16:
Hi @crob11

klingt für mich ebenfalls nach HW-Fehler... Ggf. einfach mal den develop-branch ohne HW-buttons (via webinterface) testen.

Best,
Bernd

FrankX0, 2018-09-20:
> Nach Trennen der Stromzufuhr und wiederverbinden funktionieren die Buttons nicht mehr.
This certainly sounds like a hardware issue.
This might be introduced by a noisy power-supply. Some of the (cheap) Chinese power supplies for LED applications produce a lot of noise, which in my case e.g. led to flickering of the LED's during operation.

Can you share your wiring diagram and maybe pictures?

bk1285, 2021-07-25:
Please reopen, if still unresolved.

Closed 2021-07-25.

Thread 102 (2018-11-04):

Problems using raspberry zero w - distortet output

atec111, 2018-11-04:
Hi all,

I've come to this project from microcontroller.net version of a wordclock with usage of STM32F103C8T6 and ESP. I've built my watch after there tutorial and it worked for some time, but always after a while it just hangs (not that smart for a smartlike clock ;-)). I assume the problem was the ESP and my Wifi. But never found out.

I was very happy hearing of this project, because i like raspberries a lot more than arduinos or ESPs. But unfortunately it did not work out of the box for me :-(

Symptom:
Application starts without errors. But Time as Words is lighted in different colors the same time, and not at the right place or amount (tried both wirings in the config). Other Plugins are also not working correctly. The best result comes with "rainbow" - it shows a correct horizontal Rainbow, but with decent flickering with wrong colors from time to time (more in the upper half, than in bottom).
But the good thing - it seems all LEDs can blink =)

What I did:
Almost everything what needs to be done on an brandnew from the scratch zero W. I've also done everything from Troubleshooting (using level shifter, same ground) and from closed threads (autostart in cron and no hello message).

My Wiring (as in Mikrocontroller.net):
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

A Good shot from the Rainbow:
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

And one from Time as Words (german) (should show 15:20 Uhr):
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

I've just an 5V/4A Power Fuse, could that be the Problem? Or do I need something between level shifter and data-IN from WS2812?

Regards

FrankX0, 2018-11-04:
These symptoms suggest a noise problem, normally associated with not using a level shifter and/or a noise power-supply. As you already are using a level shifter this leaves the power supply.
For my clock I initially used a cheap Chinese power supply, which caused similar problems and even destroyed the first LED of the clock due to excessive noise.
Can you try to power your clock with a (5V) power-bank: if this works correctly you need to search for a new (maybe lower power rating) power supply. I use a 3A type. A lower power rating will also be less noisy.

Hope this helps.

bk1285, 2018-11-04:
Hi @atec111

I suspect at least two issues
#1: A hardware issue as mentioned by @FrankX0
#2: The need of a correct wiring. I updated the develop branch according to your wiring posted aboved: https://github.com/bk1285/rpi_wordclock/commit/a394b1d15079d601f75d70eb59ea3f57907ce7af
Ensure to set the wiring_layout to micro_net_wiring within your config-file.

Best,
Bernd

atec111, 2018-11-06:
Hi all,

Thanks Bernd, your Wiring-Layout helped a lot. The correct words/letters are lit now.
But additionally I assume that my power supply is not the perfect one. I was testing the clock when it was attached to a "power-cube" (multiple power plugs), and it seems, that some other device caused the worst of the distortions - when I attached it back to it's target destination (a single power-plug), the flickering/ghosting was mostly gone.

Now also the animations like sunrise work, despite some little misslighting of some letters from time to time.

I think it is necessary to change the power supply as the next step. Are there any recommendations? (Clock is mounted approximately 1,8m above a power-plug)

Regards,
Andre

atec111, 2018-11-12:
Update:
I've soldered an Micro-USB-Female Port to my Circuit and tryed a Power Bank (Anker, 5V/2A). Result: It was worse than my prior 5V/4A Power Supply. More flickering in Rainbow, more wrong lit lights in "the time".
I've even tried a strong Micro-USB Power-Supply (Anker, with 5V/2.4A per Port). Result: Even more worse than the Power Bank. In Rainbow there was almost no correct picture and it was flickering so slow, that it was kind of wandering of single pixels - was looking kind of space invaders :-)

I've put my old Power-Supply back to the Clock. I've read in the web, that some guys powering a WS2812 could obeserve that the flickering would minimize, when using full brightness. I also tested this - with very good results.
With brightness be less than 100 = Not usable. With brightness at max (255) very very few flickers in rainbow, and they getting even fewer with the time the clock is powered.

So far so good. Clock is usable, but full brightness is not the best solution. **Anyone any Idea what could be done to solve the same result in the same way?** I've read on the web, that using a Capacitor (bigger=better) on Data-Pin could/should help... Others say a 1K Resistor should. But there is never a really plausible electrical statement why that should help...

Regards,
Andre

FrankX0, 2018-11-12:
Hi Andre,

As the power supply seems to be sufficient, I would guess it is due to the wiring.
Can you share in detail how you have wired your clock, starting from the power source?

When you set the clock to a stable (non changing) display, do you the also see the flickering? Or do yo only see flickering when the contents changes (like the rainbow)?
Can you disconnect the data line after a LED patterns is set? And then check for flickering?
@bk1285: do you only send new data when required (so in case of the clock only every minute)?

For your information: I am running my application also with a zero W without any flickering.

HeerNMeester, 2018-11-16:
I had similar problems after a power outage.
I did not use a level shifter before but got the same results after installing one. In the end I replaced my RPi Zero V1.3 for a RPi Zero W. That solved the problem. My conclusion: the Pi died during the power outage or at least something on the GPIO.

FrankX0, 2018-11-16:
My guess would be that the dataline from the Pi to the level shifter and/or from the level shifter to the first LED is being disturbed. Either by external noise or by distortion due to return currents.
If not done already, can you run a 0V connection close to the dataline from the Pi I/O connector to the 0V of the level shifter and from the level shifter to the 0V of the first LED?

bk1285, 2018-11-18:
>  @bk1285: do you only send new data when required (so in case of the clock only every minute)?
Yes, only once per minute.

FrankX0, 2018-12-09:
@atec111 did you succeed resolving your issue?

phenze, 2018-12-13:
Hey guys,

i had this issue several times in the last two years since i built my clock.
The Clock is working and sometimes colors are very strange and flickering around.
Then after a while everything is normal again. Then again flickering.

I do not use a level shifter. As a power supply i use 5V/10A.

In my case it was everytime a broken led in the stripe or wrong connections between the stripes.
I think i have a very bad stripe.
I don't know but a broken LED could lead to a wrong data signal ? Couldn't it ?
I'm not a hardware specialist.
That also explains why the rainbow plugin is working best. There the data is sent very very often so that a wrong signal produced by a broken LED will not have that much effect.

But in Bernds wordclock software the signal is only sent every minute.

My solution was the following :

Did you try the strandtest example ?
In my case i have modified it a bit that only the color wipe(turning ON each led individually ) is done.
When running the example i can see exactly which LED has the error.

After that i cut the strip and replaced the broken LED. Then everything is running well again.

A modified strandtest example i have uploaded here:
https://github.com/bk1285/rpi_wordclock/issues/106

Tetrikus, 2018-12-13:
Same for me, when I've built my own Wordclock. I do use capacitors and LevelShifter, but whenever I have these issues, it's one of the following:

- Hardware defect of one LED
- Loose contact on the GPIO-Header
- Loose soldering contact of the signal

atec111, 2018-12-13:
I assume the same for my clock. But I think it is more a loose contact somewhere on data-wire.
But unfortunately I hadn't enough time for detailed analysis until now. I hope xmas holidays will give me some ;-)
I'll keep you updated.

bk1285, 2021-07-24:
Reopen, if still unresolved.

Closed 2021-07-24.

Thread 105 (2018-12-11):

Wrong LEDs light up

EstherJohanna, 2018-12-11:
Hallo Bernd, vielen Dank für die ausführliche Anleitung! Die Wordclock ist unser erstes Raspi-Projekt und wir haben die LEDs tatsächlich zum Leuchten gebracht. Leider zeigen sie nicht die richtigen Wörter an. Nun fragen wir uns, an welcher Stelle wir etwas falsch gemacht haben. Wir haben dein Wiring benutzt, aber keine Buttons angebracht. Deshalb haben wir bei der Anzahl der LEDs das +4 auskommentiert und das Wordclock Interface auf type = gpio_high gestellt. Das Foto zeigt unseren Aufbau. Viele Grüße, Laura und Esther

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

bk1285, 2018-12-12:
Hallo Laura, hallo Esther,

auf dem Bild sind die 110 LEDs für die Buchstaben zu sehen, die 4 Minuten LEDs fehlen da noch: 2 direkt am Raspberry, 2 am Ende des LED-Strips.

Wenn's danach noch Probleme gibt, einfach nochmal melden.

Viel Erfolg!
Bernd

bk1285, 2018-12-12:
... siehe auch: https://github.com/bk1285/rpi_wordclock/blob/master/wordclock_layouts/german_11x10/wiring_front_bernds_wiring.png

bk1285, 2018-12-30:
Bei weiteren Fragen issue bitte wieder öffnen.

Closed 2018-12-30.

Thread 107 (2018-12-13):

Hardware recommendations

phenze, 2018-12-13:
Since a few people(including me) have several problems with their LED stripes can anybody recommend any LED Stripe which is working without trouble ?

Perhaps we can update the hardware list in the documentation with some points you have to pay attention when buying the hardware ?

It is kind frustrating when building the clock with cheap/broken LED Stripes and then searching errors for weeks.

phenze, 2018-12-14:
Hello @FrankX0 ,
thank you for your input! (and for the great new Web Interface by the way !!)

Regarding your points i have the following input:

1. I will try this. Thank you. Is it complicated to connect the level shifter ?
2. Im wondering about that point. When you use the power supply you mentioned you have not enough power to get full brightness. The Strip you have mentioned have a Power Consumption of 18W/m (i guess thats for 60led/m). So our strips will have 9W/m. This means we need about 7A to get the full power ( 9W / 30 led = 0,3 W/led --> 114*0,3 / 5 = 6,84A). Do you have full brightness with your power supply ?
3. Do you have any recommendations for "soldering noobs". Is there any easy way to connect the strips ?
4. Don't know what that means ? Sorry.

kimthostrup, 2018-12-14:
HI @phenze
For point number 3, I have considered using these : https://www.ebay.com/itm/232374294719

phenze, 2018-12-14:
@kimthostrup that's great !

Thank you !

MaxZimmermann99, 2018-12-14:
Setup which works for me right now:

LED:
https://www.amazon.de/gp/product/B07439RXD3/ref=oh_aui_detailpage_o01_s00?ie=UTF8&psc=1
PI:
Raspberry Pi Zero
Power:
https://www.amazon.de/gp/product/B00MWQF08C/ref=oh_aui_detailpage_o02_s00?ie=UTF8&psc=1

Pi powered with 5V from LED power supply (did not work with Pi on USB)
No levelshifter
No buttons

Working fine, power supply only getting warm with all LEDs turned on.

ruedli, 2021-05-03:
Regarding the power supply: I have built 3 clocks where I for each use an old notebook power supply (23V) and I use 5V step-down convertors to step down to 5V. I use minimal 5: one for the Pi and 4 for 4 groups of LEDS. The ground is common for all step-down convertors. All 3 clocks work. Advantages:
- No voltage loss over the cable of the otherwise 5V power supply, when you loose voltage of the 23V, it is compensated by the subsequent step-down convertor.
- The step-downs are quite close to the LEDS, so less power loss with the 5V circuitry.
- No common 5V between Pi and LEDS
- So far no interference, the clocks are running for many years now, I am building the 4th one now.

Because I also use servos and motors in my clocks, they use different step-downs set to 6V.

The build deviates from the current description, but so far my experience is quite good. Anyone else gone this route?

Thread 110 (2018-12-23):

Touching the Raspi crazy effects

MaxZimmermann99, 2018-12-23:
Hey guys if i touch my rasp zero with my finger it makes random stuff like changing the colour or starting random plugins.
I have no buttons and my config says "gpio_high".

Sometimes its even enough to touch the wood of the frame :) Not sure whats going on. My data cabel is soldered to the raspi so its not a buggy jumper cable...

Merry Chrismas everyone!

bk1285, 2018-12-23:
Hey @MaxZimmermann99,

did you setup one common ground? Raspberry + LEDs?

Best,
Bernd

MaxZimmermann99, 2019-01-19:
Sorry took me some days to get back here.

I have a common ground for the pi and the LEDs. Without this it wasnt working at all. https://github.com/bk1285/rpi_wordclock/issues/106

I really dont know what causes these effects. I'm gonna keep on reporting. Maybe the next clock is gonna be different :)

bhunziker, 2019-03-12:
Is it different if you pull the inputs to ground? It might be some cross-talk from the LED output

MaxZimmermann99, 2019-05-16:
Hey again everyone. I started over again. New Clock, new Raspberry Zero W, new 5V power and the same problem.

I dont use any buttons and i tried gpio_high and gpio_low. I also tried to use a groud pin for all 3 buttons in the config but the clock won't start this way. Same with some random non existend pin numbers.

Not sure how i am the only one with this problem as i'm using the very basic setup....
And not sure if anyone is still reading this post :)

Should i try to connect all 3 button pins with ground and use gpio_high?

Greetings
Max

P.S. Yes my drawing sucks but it should make clear how my setup looks like. (no buttons, no sensor, nothing else...)

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

bhunziker, 2019-05-25:
The only thing I could recommend you is what you proposed: all non used pins on ground.
btw: have you tried it with a very clean installation from github? Just in case it might be a software problem.

Greetings
Bernhard

Patrik42, 2019-06-30:
Hi All,
same problem at my end.
I have got common ground, RPI 3b.

Additionally, the startscript via crontab does not work.

The log shows

  File "/home/pi/rpi_wordclock/wordclock.py", line 167, in <module>
    word_clock.startup()
    self.wcd.showText("IP: " + netifaces.ifaddresses(interface)[2][0]['addr'])
KeyError * Serving Flask app "wordclock_interfaces.web_interface" (lazy loading)
:  * Environment: production
2   WARNING: Do not use the development server in a production environment.

   Use a production WSGI server instead.

Do I need to change the environment of Flask?!

SvenFackert, 2019-12-07:
For everyone who stumbles across this problem in the future (no hardware buttons), I have a very simple solution for you. I had the same problem for one of my builds that had no buttons. In these cases touching the pins of the Raspi will eventually trigger the button functions.

The simplest solution in my opinion is to just disable the event listeners for the buttons in the wordclock_interfaces/gpio_interface.py file. Open the file e.g. in nano (sudo nano rpi_wordclock/wordclock_interfaces/gpio_interface.py) and comment out the following lines (by inserting the hash/number sign at the beginning of each line):

`#        GPIO.add_event_detect(self.button_left,
#                              self.polarity,
#                              callback=lambda channel: self._left(),
#                              bouncetime=100)
#        GPIO.add_event_detect(self.button_return,
#                              self.polarity,
#                              callback=lambda channel: self._return(),
#                              bouncetime=100)
#        GPIO.add_event_detect(self.button_right,
#                              self.polarity,
#                              callback=lambda channel: self._right(),
#                              bouncetime=100)`

Finally CTRL + O, ENTER to save your changes and CTRL + X to quit nano.

Maybe this could also be configured in the config file in future versions. E.g. a property "disable_hardware_buttons".

mrksngl, 2019-12-10:
The hardware fix would be to hardwire the corresponding gpios to ground (or VCC, depending on the polarity setting) :)

But yes, we should also give it a property, as it seems there is a use case for having no buttons.

bk1285, 2021-07-24:
Reopen, if still unresolved.

Closed 2021-07-24.

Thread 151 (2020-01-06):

Problems with Raspberry Pi Zero W and the W2812B LEDstrip

BowenDragonheart, 2020-01-06:
Hi WordClock makers!,

I am trying to build my own Word Clock and am in the final stage of testing the LED strips. Unfortunately, I ran into problems here.

I'm using a Raspberry Pi Zero W, combined with a Mean Well power supply (5V, 50W) and the a W2812B LEDstrip.

Using both the strandtest.py and the test script of the source directory, I run into a strange problem: I need to specifiy four more LEDs than are actually in the LEDstring to have all light up.

To investigate more, I made a simple program based on the strandtest.py and an issue raised in the rpi_ws281x github (https://github.com/jgarff/rpi_ws281x/issues/314) .

----------------------------------------------------------------------------------------------------

from neopixel import *

LED strip configuration:
LED_COUNT = 10 # Number of LED pixels.
LED_PIN = 18 # GPIO pin connected to the pixels (18 uses PWM!).
#LED_PIN = 10 # GPIO pin connected to the pixels (10 uses SPI /dev/spidev0.0).
LED_FREQ_HZ = 800000 # LED signal frequency in hertz (usually 800khz)
LED_DMA = 10 # DMA channel to use for generating signal (try 10)
LED_BRIGHTNESS = 255 # Set to 0 for darkest and 255 for brightest
LED_INVERT = False # True to invert the signal (when using NPN transistor level shift)
LED_CHANNEL = 0 # set to '1' for GPIOs 13, 19, 41, 45 or 53

strip = Adafruit_NeoPixel(LED_COUNT, LED_PIN, LED_FREQ_HZ, LED_DMA, LED_INVERT, LED_BRIGHTNESS, LED_CHANNEL)
strip.begin()

strip.setPixelColorRGB(0, 127, 127, 127)

strip.show()

----------------------------------------------------------------------------------------------------

If I run this, the first LED become white. So far so good. If also the second LED is activated,

strip.setPixelColorRGB(0, 127, 127, 127)
strip.setPixelColorRGB(1, 127, 127, 127)

then the first remains white, but the second becomes yellowish green. If also the third is given a signal

strip.setPixelColorRGB(0, 127, 127, 127)
strip.setPixelColorRGB(1, 127, 127, 127)
strip.setPixelColorRGB(2, 127, 127, 127)

Then the first and second become white and the third bright green.

To conclude

strip.setPixelColorRGB(0, 127, 127, 127)
strip.setPixelColorRGB(1, 127, 127, 127)
strip.setPixelColorRGB(2, 127, 127, 127)
strip.setPixelColorRGB(3, 127, 127, 127)
strip.setPixelColorRGB(4, 127, 127, 127)
strip.setPixelColorRGB(5, 127, 127, 127)
strip.setPixelColorRGB(6, 127, 127, 127)
strip.setPixelColorRGB(7, 127, 127, 127)
strip.setPixelColorRGB(8, 127, 127, 127)
strip.setPixelColorRGB(9, 127, 127, 127)

Results in that the first seven are white, the 8th is yellow and LED9 and LED10 are not giving light at all.

I tried with several LED strips of 10 and all gave the same result.

Who can help me to solve this? I also made an issue at the rpi_ws281x github, but there people appear not to be that active.
.
You will have my eternal gratitude if you can help me with this.

Best regards,
Bart

plotaBot, 2020-01-07:
Hello @BowenDragonheart,

welcome to the Wordclock builders.
I have three things you might consider to get rid of that behaviour:
1. Are you using this commit of rpi_ws281x as described in [Software Setup](https://rpi-wordclock.readthedocs.io/en/master/doc_software_setup.html#rd-party-dependencies-git-repositories)?
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
2. Remove the level converter. (I am also using a Rpi Zero W and the LEDs light up fine witout one.)
3. Swap the Meanwell with an USB wall adapter. (Maybe this is a better and safer solution.)

Greetings, plotaBot

BowenDragonheart, 2020-01-07:
Thank you for your input!

1. Yes, but I will do a clean install right now just to make sure that everything.
2. I don't use a level converter.
3. I will give this a try.

Furthermore, I have read that it is important that the LED strip and the PI do not share the 5V+
(https://tutorials-raspberrypi.com/connect-control-raspberry-pi-ws2812-rgb-led-strips/)

This is currently the case for my clock. Why is this important? Can this explain the wrong behaviour?

plotaBot, 2020-01-07:
Ok. Have you connected both Ground (Power Pi AND Power LEDs) to the Pi?
I am not experiencing any kind of problems using one Powersupply. My wiring looks like this:
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

Maybe another thing causing this problem could be related to the beefy powersupply iterfering with the signals. btw: 10-15W should be enough and an ordinary phone charger is capable to deliver such power. Since you are not running all 114 LEDs at the same time on white with maximum brightness you should be fine. (I once measured this value and Pi + all LEDs were using <2A peak)

Let us know if anything I suggested works or not ;)

BowenDragonheart, 2020-01-07:
Wait, do you need also to connect the last LED to the +5V and the GND? :O

BowenDragonheart, 2020-01-07:
Is that not the problem? It is not an RGB strip, but a RGBW strip. Is this not supported?

plotaBot, 2020-01-07:
Apparently rpi_ws281x supports RGBW but implementing it requires more effort and a strip at hand. Sorry if you bought the wrong LED strip.
Unfortunately I am currently not able to develop a rpi_wordclock RGBW support (time and no LEDs). Or you, Bowen, are passionate enough to dig into that?

@bk1285: Would you add the enhancment label so @BowenDragonheart is able to use his LEDs (somewhere in the future).

bk1285, 2020-01-25:
Hi @BowenDragonheart

to address the LEDs, jgarff's library is currently used. As mentioned [here](https://github.com/jgarff/rpi_ws281x/issues/387#issuecomment-574727119), it's probably an issue, that you need to provide another byte to setup the fourth color channel. As soon, as jgarff's library supports this, I expect the wordclock to work smoothly with th RGBW-type of LEDs.

Meanwhile, you'll have to choose standard RGB-strip.

Best,
Bernd

Closed 2020-01-25.

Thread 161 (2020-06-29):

colorful light up

nUmb3rfive, 2020-06-29:
Hi guys,
first of all, you did an awesome job creating this software! Thank you very much!
Unfortunately some issues are occurring in recent times. There appears sometimes a color pattern for 1 minute until the time changes (attached a picture). The LEDs also flicker in rainbow mode despite the use of a level shifter. Do you guys have any idea how to fix this issue?
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
Thanks for your help in advance. If you need more informations for troubleshooting do not hesitate to ask.
Cheers,
Nicola

FrankX0, 2020-07-02:
Always difficult to debug this from a distance.
All points to noise on the data line to the LED's, causing them to flicker or turn on, which is "corrected" when the actual time is written again. Good that you use a level shifter!

Did you try a different power-supply?
Can you make pictures (or drawing) of how your power (especially ground) and signal connections are running?

echo1483, 2020-07-03:
Hallo Nicola,
hat zwar nichts damit zu tun. Was hast du als Streuscheibe für die LED´s benutzt.
Danke, echo

nUmb3rfive, 2020-07-04:
No, it‘s actually difficult to find such a powerful power supply. I ordered this one directly in China.
Specs of my power supply:
- Input Voltage: 100~240V AC
- Output Voltage: 5V DC
- Output Current: 10A
- Suggested Usage: LED display, communication

Thank you for your help! I really appreciate it!

@echo1483 : In my opinion PLEXIGLAS® of evonik works best as a diffusor for the wordclock. I used PLEXIGLAS® Resist WHITE 99532 GT, thickness: 0.5mm. I hope this helps.

More pictures:
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

echo1483, 2020-07-05:
Thank you for your prompt reply.
echo

phenze, 2020-07-06:
Take a look here:

* https://github.com/bk1285/rpi_wordclock/issues/110
* https://github.com/bk1285/rpi_wordclock/issues/106

Looks like you have no common ground.

bk1285, 2020-12-19:
Reopen, if not resolved.

Closed 2020-12-19.

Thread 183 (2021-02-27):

Leds reset after each minute

wiefeli, 2021-02-27:
I made a wordclock and everything seems fine, but the Leds are blinking each minute. It seems like they are resetted each minute. Is there a way to enable the feature that only the "new" Leds light up and not a full reset every minute?

FrankX0, 2021-03-03:
What you are facing is not normal behavior. The LEDs are not supposed to blink every minute: the ones which should be off turn off, the ones which should be on turn on.
Maybe it’s related to your power-supply? Is the current rating sufficient?
Do you see the blinking only during the clock feature, or also with the other features (matrix, rainbow, etc.)?

wiefeli, 2021-03-03:
It's only with the time default plugin. The matrix, rainbow,.... are working perfect. It seems like checking the time every minute and therefore resetting each time

phenze, 2021-03-04:
Which Branch are you working on ?
Are you running on python2 or python3 ?
Which raspbian version are you using ?

I think your power supply is not enough at max power consumption:
- LED's : 114*0,06 = 6,84 A
- Raspberry 3: 1,8 A

On Top the PI 3 has a construction error which drops 0.6 V anywhere on the board. I don't know the exact problem.
But as far as i know the PI 3 is only working properly with the official power supply which has a power output of 5.2 V!
So try getting this official power supply and try powering the PI separately.

wiefeli, 2021-03-04:
But the LEDs need the max power only when all leds are up.

However I think this is not the issue, since I had a similar setup with this Pi and it was working properly (but with older branch) but had to build everything from scratch again and now this issue appeared.

bk1285, 2021-03-04:
Tanks for reporting

Possibly caused here: https://github.com/bk1285/rpi_wordclock/blob/8e2e57fadb5b70c8e3de3a8df0c83fe144e30fbe/wordclock_plugins/time_default/plugin.py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

Requires a bug fix to allow further options than only fadeOutIn or typewriter...

Regards,
Bernd

luchs7, 2021-04-20:
Thanks for the great work that has been done around the wordclock.
I was also not happy with the fadeOutIn option and was happy to see the comment above.

The code to display the LEDs (wordclock_display) offers 3 options: typewriter, fadeoutin and no animation.
The config file allows to set a varable typewriter to true/false (2 Options).
The plugin time_default allows only typewriter (true) and sets it to "fadeOutIn" otherwise.

As a workaround I changed the else value in the line mentioned above (anything other than typewriter or fadeOutIn) to trigger the 3rd option. E.g. self.animation = "typewriter" if self.typewriter else "None"

Not a fix but the result is ok.

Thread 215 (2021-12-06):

Nearly finished..

tom4727, 2021-12-06:
Moin. I just see the finishline :-)

Just after

cd ~/rpi_wordclock
sudo python wordclock.py

Raspberry says:

ModuleNotFoundError: No module named „ConfigParser“.

Can anybody help?

Calimerorulez, 2021-12-06:
https://techglimpse.com/fix-no-module-named-import-error/

Maybe this helps?

phenze, 2021-12-07:
Which python version are you using ?
```python --version```

Which Raspian Version have you installed ?

You should use python3 instead of python2.

Take a look at this discussion:
https://github.com/bk1285/rpi_wordclock/issues/211

tom4727, 2021-12-11:
Moin, my version is Python 3.9.2. another prob is that sudo scons is allready missing.

tom4727, 2021-12-11:
>
$pip install configparser
Collecting configparser
Using cached configparser-3.3.0r2.tar.gz
Building wheels for collected packages: configparser
Running setup.py bdist_wheel for configparser
Stored in directory: /root/.cache/pip/wheels/1a/3e/f9/d34006ad6b1edfe5006aa704f5ee305c553344a7a6d8550c29
Successfully built configparser
Installing collected packages: configparser
Successfully installed configparser-3.3.0.post2
install: Fehlender Zieldatei‐Operand hinter 'configparser'
„install --help“ liefert weitere Informationen.
bash: Collecting: Kommando nicht gefunden.
bash: Using: Kommando nicht gefunden.
bash: Building: Kommando nicht gefunden.
bash: Running: Kommando nicht gefunden.
bash: Stored: Kommando nicht gefunden.
bash: Successfully: Kommando nicht gefunden.
bash: Installing: Kommando nicht gefunden.

tom4727, 2021-12-11:
sudo: scons: Befehl nicht gefunden

tom4727, 2021-12-11:
thank you for your help and kindness. now there is that issue:

sudo pip3 install ConfigParser
Looking in indexes: https://pypi.org/simple, https://www.piwheels.org/simple
Collecting ConfigParser
  Downloading https://www.piwheels.org/simple/configparser/configparser-5.2.0-py3-none-any.whl (19 kB)
Installing collected packages: ConfigParser
Successfully installed ConfigParser-5.2.0
pi@raspberrypi:~ $ cd ~/rpi_wordclock
sudo python wordclock.py
Traceback (most recent call last):
  File "/home/pi/rpi_wordclock/wordclock.py", line 1, in <module>
    import ConfigParser
ModuleNotFoundError: No module named 'ConfigParser'

FrankX0, 2021-12-11:
I would advise to use the develop branch:
`https://github.com/bk1285/rpi_wordclock/tree/develop`
with its installation instructions.

tom4727, 2021-12-12:
thx FrankX0 :-)  i think this solved my issue. the cronjob is now working (i think). now i will get all the components together and will have a look, if all is working togehter.

RahulYadav2207, 2022-01-31:
i also got same error

RahulYadav2207, 2022-01-31:
@tom4727 what to do if i got the same error which you got No module named 'ConfigParser'

phenze, 2022-01-31:
Reading the instructions here :

* https://github.com/bk1285/rpi_wordclock/tree/develop
* https://github.com/bk1285/rpi_wordclock/issues/211

or all the instructions in this issue.

I think your main problem is that you dont use python3 (https://github.com/bk1285/rpi_wordclock/issues/211#issuecomment-966865031)

RahulYadav2207, 2022-01-31:
i used

RahulYadav2207, 2022-01-31:
@phenze can you please explain me in detail how to setup all things plz

phenze, 2022-01-31:
Did you switch to the development branch ?

`git checkout --track origin/develop`

RahulYadav2207, 2022-01-31:
What's this how can i access this in rpi terminal

phenze, 2022-02-01:
That is all explained here:
https://github.com/bk1285/rpi_wordclock/tree/develop

```
git clone https://github.com/bk1285/rpi_wordclock.git
cd rpi_wordclock/
git checkout --track origin/develop
```

Do you know how to use a Linux Terminal and what the commands are doing ?
If not do this tutorial:
* https://ubuntu.com/tutorials/command-line-for-beginners#1-overview

For a basic overview what git does:
* https://rogerdudler.github.io/git-guide/

FrankX0, 2022-02-01:
@bk1285: this might be a good time to make the develop branch the new main branch?

bk1285, 2022-09-01:
Done, @FrankX0 :)

Closed 2022-09-01.

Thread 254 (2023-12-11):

LEDs not working

MichaelSeitz98, 2023-12-11:
Hi guys,

Thanks for this cool project. I am (trying to) create a word clock for a surprise Xmas present.

- I have set up the hardware and was able to successfully run the software on the device.
- However, the LEDs do not light up at all.
- Sometimes the first two (single, like Bernd's wiring) LEDs will light up, but very erratically, and now not at all.
- I do not get any error messages from the software side...
- I did not adjust the config file ( in my opinion no need, as same configuration as @bk1285 )
- I did not yet build in the buttons as I wanted to test the setup first

Do you experts have any idea what is going on here? Any idea would save me from my desperation 😁
Do I need the buttons to make the functionality work?

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

Thanks and all the best !
Michael

P.S: falls ihr auf deutsch antworten mögt, geht das auch gerne klar ;)

phenze, 2023-12-11:
Hi,
lies dir mal die 4 Issues durch.

https://github.com/bk1285/rpi_wordclock/issues?q=is%3Aissue+common+ground+

Dein Problem ist dass du kein common ground hast. der Minuspol vom Netzgerät muss mit nem minuspol vom raspberry verbunden sein.

Außerdem sehen deine Lötverbindubgen echt nicht gut aus. Miss da mal durch ob auch überall was anliegt. achte auch darauf dass du keinen kurzschluss hast.

Wenn alles nichts hilft kannst du noch noch in der Mitte von jedem Steifen jeweils den minus und pluspol verbinden

phenze, 2023-12-11:
Kurzschluss merkt man normal schnell.

Die streifen werden dann sehr warm und der raspberry sollte abschalten.

Probier das mit dem strandtest (ist in einem der beiträge erklärt ) mal aus. das ist die einfachste methode zu prüfen ob mit dem led streifen alles passt.

MichaelSeitz98, 2023-12-12:
Hi @phenze

danke nochmals für deine Antwort!

### Ich hab mittlerweile die folgenden Dinge ausprobiert (Spoiler: leider ohne Erfolg):

*  versucht den Common Ground zu verbinden: habe den Ground (Schwarz) des Netzteils auf einen Ground des PIs gesteckt. (siehe Bilder).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
 Aber leider ich bekomme dasselbe Resultat: nur die ersten beiden LEDs leuchten und das auch ziemlich willkürlich. Und die
 reagieren auch manchmal auf Druck/Berührung.  Daher bin ich mir irgendwie nicht mehr sicher, ob ich das richtig gemacht hab.
 Was sagst du dazu?
* Auch [diesen](https://github.com/rpi-ws281x/rpi-ws281x-python/blob/master/examples/strandtest.py) strandtest.py habe ich gestartet. Das Programm dazu läuft ohne Fehlermeldung, aber auch hier gibt es ein ähnliches Ergebnis: nur die ersten zwei LEDs und willkürlich.
 Hast du da zufällig auch eine Idee dazu? Wäre dir natürlich um jede Hilfe sehr dankbar!

### Meine nächsten, verzweifelter Versuch wäre der folgende
1. Ein neues LED-Band kaufen
2. Alles 114 LED am Stück lassen und anschließen (dann muss ich nur 3 Lötstellen setzen und kann schlechte Lötstellen/LEDs ausschließen)
3. Dann nochmals versuchen das Programm zu starten.

Macht der Plan für dich Sinn?
### Meine verwendete Hardware:
* Raspberry PI 3 B
* LEDs: https://www.amazon.de/dp/B09LTT1PBX?psc=1&ref=ppx_yo2ov_dt_b_product_details
* Netzteil: https://www.amazon.de/dp/B08SVX1TH5?ref=ppx_yo2ov_dt_b_product_details&th=1

Besten Dank und schon mal eine schöne Adventszeit!
Michael

phenze, 2023-12-13:
Also schwarz ist dein Datenkanal. Der muss auf Pin 12.
Braun ist dein Ground. Der muss auf Pin 6,9 oder 14. Meiner ist auf 9.

Pinbelegung wie auf dem bild im Anhang.

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

Verwende bitte mal das Strandtest Example aus dem Thread hier: https://github.com/bk1285/rpi_wordclock/issues/106

Das ist so umgeschrieben dass es einfach der Reihe nach alle LED's durchschaltet. Ideal zum Testen.

Wenn iwas auf Druck/Bewegung reagiert sieht das sehr nach kalten Lötstellen aus (leider) . Da hilft nur Löten üben. Ein neuer Streifen bringt da meiner Meinung nach nicht viel.
Du kannst auch während der Test läuft einfach mal den Streifen biegen und an den Lötstellen drücken. Dann sieht du den Fehler evtl.

Probier doch erstmal anstatt der einzelnen LED am Anfang einfach einen längeren Streifen an erster Stelle anzulöten und prüfe was dann passiert. Gerade die einzelnen LED's fallen bei mir auch immer mal wieder aus (Bin auch kein Löt Experte).

Hier noch ein Bild wie ich das gelötet habe. Seitdem ich +/- nur in der Mitte verbunden habe und nur den Datenkanal außen funktioniert das bei mir viel stabiler.

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

MichaelSeitz98, 2023-12-14:
Hi,

Danke mal wieder!

* Dein umgeschriebenen Strandtest.py aus #106 konnte ich nicht 1:1 ausführen, weil ich da einen Error bekommen für Zeile 21: `LED_STRIP = ws.WS2811_STRIP_GR`, weil `ws` nicht bekannt ist. Hab dann `from rpi_ws281x import ws, Color, Adafruit_NeoPixel'  importiert und dann war er aufführbar, aber die komische Effekte bleiben (s. unten).

* Ich hab jetzt doch einfach mal den neuen Streifen angeschlossen und _Strandtest.py_ aus dem Ordner [example](https://github.com/rpi-ws281x/rpi-ws281x-python/blob/master/examples/strandtest.py) (auf 114 LEDs angepasst und nur den ColorWipe dringelassen) ausgeführt. Dann bekomme ich erneut ein sehr komisches Resultat: Es leuchten einige LEDs (siehe Bild), aber nicht alle. Die LEDs wechseln manchmal willkürlich, manchmal auch auf Kontakt.
* Falls das irgendwie noch klappen sollte, schulde ich dir @phenze auf jeden Fall ne Menge!

Hier noch Bilder bzw. Video vom Debakel 🤣
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

https://github.com/bk1285/rpi_wordclock/assets/65539604/a4c29138-1da4-436b-bf48-bc2576ca757e

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

https://github.com/bk1285/rpi_wordclock/assets/65539604/424f64a3-d2e6-4ef2-accc-8699d0ee90a7

phenze, 2023-12-14:
Probiere mal bitte noch die anderen konstanten für LED_STRIP aus.

Die findest du hier: https://github.com/jgarff/rpi_ws281x/blob/master/ws2811.h

Ich glaube aber dass bei dir der pluspol einen kurzschluss auf den Datenkanal hat.
Schließe doch einmal +/- eine Ebene weiter hinten an und nur den Datenkanal vorne (wie bei mir auf der Uhr).

Wenn das alles nicht hilft würde ich das System nochmal komplett neu aufsetzen. Sprich Raspbian nochmal komplett neu installieren.

Und wenn das alles nicht hilft weis ich leider auch nicht mehr weiter. Dann kann es euigl nur noch ein defekter Streifen oder Raspberry sein.

phenze, 2023-12-14:
Ahh. Du hast einen Ws2812b und keinen Ws2811b. (12 statt 11).

Das könnte natürlich auch noch ein Thema sein. Dafür gibt es aber auch Konstanten in dem File oben.
Probier das einfach mal aus.

MichaelSeitz98, 2023-12-14:
Hab mal die Konstanten ausprobiert und vor allem auf die ws2812 umgestellt. Leider auch wieder ohne Erfolg, sondern wieder mit willkürlichen LED-Aktionen beim strandtest. Starte jetzt nochmals von ganz vorne :) wenn das nicht klappt, werde ich wohl einfach ein neuen Raspberry PI versuchen und einen neuen LED Streifen. Wenn das auch nicht hilft, muss ich wohl leider aufgeben 😞

Könnten die Buttons bzw. die dazugehörigen Widerstände eine Rolle spielen? Soll ich die einfach mal anschließen?

phenze, 2023-12-14:
Nein der Strandtest weiß ja gar nichts von den Buttons. Und auch in der Wordclock Software kannst du diese deaktivieren.

MichaelSeitz98, 2023-12-14:
Danke! Dann werde ich mal einen neuen ED-Streifen und Raspberry Pie versuchen und einen Level Shifter versuchen einzubauen.
Danke für deine Hilfe!

MichaelSeitz98, 2023-12-15:
Update: scheint als sei der fehler endlich behoben. Es lag tatsächlich am Raspberry Pie!
Ich konnte die LEDs nun anschließen und der strandtest lässt sich endlich mit sinnvollen ergebnissen ausführen.
Einen kleineren Haken gibt es aber noch: es funktionieren nur die ersten circa 23 LEDs. Ab dann geht der Test nicht weiter.
Was wäre da deine Einschätzung dazu: den dritten Streifen auszutauschen oder auf deine Verkabelung zu wechseln?

Closed 2023-12-16.

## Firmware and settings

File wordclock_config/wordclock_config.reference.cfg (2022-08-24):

# -*- coding: utf-8 -*-

# This is an examplary configuration file.
# Copy this to wordclock_config/wordclock_config.cfg for customization

[wordclock]
show_startup_message = True

# Can be a string like "Hello world" or the keyword "ShowIP" to display the wordclocks IP-address (to access the web interface)
startup_message = ShowIP

# set animation fps (0 will not animate)
animation_fps = 25

# Set to True to run the software with GTK on a linux system
# * Does not require any wordclock hardware
# * Maps the port for web-access to 8080
developer_mode = False

# Additionally available after parsing by the wordclock-software:
# base_path = "/path/to/wordclock.py"
# e.g.: base_path = "/home/pi/rpi_wordclock"

[wordclock_display]
# set language option
language = german

# Choose wiring layout here. Options are: bernds_wiring, christians_wiring, ... (possibly you need your own wiring layout)
wiring_layout = bernds_wiring

# Fonts available at /usr/share/fonts/... (e.g. some types listed in truetype/freefont)
# FreeMono FreeMonoBoldOblique FreeSans FreeSansBoldOblique FreeSerif FreeSerifBoldItalic
# FreeMonoBold FreeMonoOblique FreeSansBold FreeSansOblique FreeSerifBold FreeSerifItalic
default_font = wcfont

# Set the brightness of the display (between 1 and 255)
brightness = 255
# Supported sensor: TSL2561
use_brightness_sensor = False
# Sensor I2C address in decimal: 41 (0x29), 57 (0x39), 73 (0x49)
sensor_address = 57

[wordclock_interface]
# Defines type of interface (gpio_low: pin is set to low on event, gpio_high: pin is set to high on event, no_gpio: no pins are read at all (= disabled hardware buttons))
type = gpio_low

pin_button_left     = 17
pin_button_return   = 22
pin_button_right    = 24

# Optional value. Uncomment, if temperature sensor is attached. E.g. at pin 4
# pin_temp_sensor     = 4

# Number of seconds a button is locked after beeing pressed (insensitivity to further touch)
lock_time           = 0.2

### Below here, the wordclocks plugin parameter are provided in alphabetical order

[plugin_feed_parser]
activate = True

# Set url to rss-feedparser
rss_url = http://www.tagesschau.de/xml/rss2

[plugin_ip_address]
activate = True

# Get ip to access the raspberry. Possible interfaces: wlan0, eth0, ...
interface = wlan0

[plugin_matrix]
activate = True

[plugin_rainbow]
activate = True

[plugin_time_in_seconds]
activate = True

[plugin_leds_off]
activate = True

[plugin_restart]
activate = True

[plugin_sunrise]
activate = True

# Choose your city from https://astral.readthedocs.io/en/latest/#cities
location = Berlin

[plugin_shutdown]
activate = True

[plugin_tetris]
activate = True

[plugin_snake]
activate = True

[plugin_time_as_words_dutch]
activate = True

[plugin_time_as_words_german]
activate = True

[plugin_time_default]
activate = True

# animation in : typewriter, fadeOutIn, none
animation = fadeOutIn
animation_speed = 5

# should every minute be animated or only every 5 minutes
play_animation_each_minute = False

# Default foreground/background colors
# BLACK, WHITE, WWHITE, RED, YELLOW, LIME, GREEN, BLUE
default_fg_color = WWHITE
default_bg_color = BLACK

# Choose the order of the pins for the minutes
# Like an analogic clock : 1,3,2,0
#  ___________
# |           |
# |  0     1  |
# |           |
# |  2     3  |
# |___________|
minutes_map = 0,1,2,3

# show time without prefix IT IS/ES IST/etc.
purist = False

# define sleep times when the display brightness is turned down [define any time with format hour:minute [0-23]:[0-59], e.g. 20:30
sleep_begin = 00:00
sleep_end = 00:00
sleep_brightness = 10

[plugin_time_matrix]
activate = True

[plugin_weather_forecast]
activate = True

# choose weather service to retrieve forecast (options: meteoswiss (note: openweathermap, only for swiss cities))
#Data for the OpenWeatherMap service
weather_service = openweathermap
api_key = Your API-key here
city = Your city here

#Data for the meteoswiss service
#weather_service = meteoswiss
#zipcode = 8606

### Below here, the wordclocks stencil parameter are provided
### E.g. to create your own/custom stencils

[stencil_parameter]
# All measures in mm
# Absolute height of the wordclock in mm
height=450
# Absolute width of the wordclock in mm
width=450
# Margin between edge and minute leds
minute_margin=20
# Diameter of the minutes
minute_diameter=5
# Height of the wordclock array
wca_height=300
# Width of the wordclock array
wca_width=300
# Font-type
font_type=Arial
# Font-size
font_size=22
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

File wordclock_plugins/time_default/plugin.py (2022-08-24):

import datetime
import logging
import os
import time
import wordclock_tools.wordclock_colors as wcc
import wordclock_tools.wordclock_display as wcd


class plugin:
    """
    A class to display the current time (default mode).
    This default mode needs to be adapted to the hardware
    layout of the wordclock (the chosen stencil) and is
    the most essential time display mode of the wordclock.
    """

    def __init__(self, config):
        """
        Initializations for the startup of the current wordclock plugin
        """
        # Get plugin name (according to the folder, it is contained in)
        self.name = os.path.dirname(__file__).split('/')[-1]
        self.pretty_name = "The time"
        self.description = "The minimum, you should expect from a wordclock."

        self.animation = ''.join(config.get('plugin_' + self.name, 'animation'))

        animations = ["fadeOutIn", "typewriter", "none"]

        if self.animation not in animations:
            logging.warning('No animation set for default plugin within the config-file. ' + animations[0] + ' animation will be used.')
            self.animation = animations[0]

        self.animation_speed = config.getint('plugin_' + self.name, 'animation_speed')

        self.play_animation_each_minute = config.getboolean('plugin_time_default', 'play_animation_each_minute')
        self.purist = config.getboolean('plugin_time_default', 'purist')

        self.sleep_begin = datetime.datetime.strptime(config.get('plugin_' + self.name, 'sleep_begin'), '%H:%M').time()
        self.sleep_end = datetime.datetime.strptime(config.get('plugin_' + self.name, 'sleep_end'), '%H:%M').time()
        self.sleep_brightness = config.getint('plugin_' + self.name, 'sleep_brightness')

        # Choose default fgcolor
        fgcolor = ''.join(config.get('plugin_time_default', 'default_fg_color'))

        if fgcolor == 'BLACK':
            self.word_color = wcc.BLACK
            self.minute_color = wcc.BLACK
        elif fgcolor == 'WHITE':
            self.word_color = wcc.WHITE
            self.minute_color = wcc.WHITE
        elif fgcolor == 'WWHITE':
            self.word_color = wcc.WWHITE
            self.minute_color = wcc.WWHITE
        elif fgcolor == 'RED':
            self.word_color = wcc.RED
            self.minute_color = wcc.RED
        elif fgcolor == 'YELLOW':
            self.word_color = wcc.YELLOW
            self.minute_color = wcc.YELLOW
        elif fgcolor == 'LIME':
            self.word_color = wcc.LIME
            self.minute_color = wcc.LIME
        elif fgcolor == 'GREEN':
            self.word_color = wcc.GREEN
            self.minute_color = wcc.GREEN
        elif fgcolor == 'BLUE':
            self.word_color = wcc.BLUE
            self.minute_color = wcc.BLUE
        else:
            print('Could not detect default_fg_color: ' + fgcolor + '.')
            print('Choosing default: warm white')
            self.word_color = wcc.WWHITE
            self.minute_color = wcc.WWHITE

        bgcolor = ''.join(config.get('plugin_time_default', 'default_bg_color'))

        if bgcolor == 'BLACK':
            self.bg_color = wcc.BLACK
        elif bgcolor == 'WHITE':
            self.bg_color = wcc.WHITE
        elif bgcolor == 'WWHITE':
            self.bg_color = wcc.WWHITE
        elif bgcolor == 'RED':
            self.bg_color = wcc.RED
        elif bgcolor == 'YELLOW':
            self.bg_color = wcc.YELLOW
        elif bgcolor == 'LIME':
            self.bg_color = wcc.LIME
        elif bgcolor == 'GREEN':
            self.bg_color = wcc.GREEN
        elif bgcolor == 'BLUE':
            self.bg_color = wcc.BLUE
        else:
            print('Could not detect default_bg_color: ' + bgcolor + '.')
            print('Choosing default: black')
            self.bg_color = wcc.BLACK

        # Other color modes...
        self.color_modes = \
            [[wcc.BLACK, wcc.WWHITE, wcc.WWHITE],
             [wcc.BLACK, wcc.WHITE, wcc.WHITE],
             [wcc.BLACK, wcc.ORANGE, wcc.ORANGE],
             [wcc.BLACK, wcc.ORANGE, wcc.WWHITE],
             [wcc.BLACK, wcc.PINK, wcc.GREEN],
             [wcc.BLACK, wcc.RED, wcc.YELLOW],
             [wcc.BLACK, wcc.BLUE, wcc.RED],
             [wcc.BLACK, wcc.RED, wcc.BLUE],
             [wcc.YELLOW, wcc.RED, wcc.BLUE],
             [wcc.RED, wcc.BLUE, wcc.BLUE],
             [wcc.RED, wcc.WHITE, wcc.WHITE],
             [wcc.GREEN, wcc.YELLOW, wcc.PINK],
             [wcc.WWHITE, wcc.BLACK, wcc.BLACK],
             [wcc.BLACK, wcc.Color(30, 30, 30), wcc.Color(30, 30, 30)]]
        self.color_mode_pos = 0
        self.rb_pos = 0  # index position for "rainbow"-mode

        self.brightness_mode_pos = config.getint('wordclock_display', 'brightness')
        self.brightness_change = 8

        self.use_brightness_sensor = config.getboolean('wordclock_display', 'use_brightness_sensor')
        self.brightness_sensor_address = config.getint('wordclock_display', 'sensor_address')

        print(('Using brigtness sensor : ' + str(self.use_brightness_sensor)))
        if self.use_brightness_sensor:
            print('Importing sensor Library ')
            import board
            import busio
            import adafruit_tsl2561
            i2c = busio.I2C(board.SCL, board.SDA)
            self.sensor = adafruit_tsl2561.TSL2561(i2c,self.brightness_sensor_address)
        # save current brightness for switching back from sleep mode
        self.wake_brightness = self.brightness_mode_pos

    def run(self, wcd, wci):
        """
        Displays time until aborted by user interaction on pin button_return
        """
        # Some initializations of the "previous" minute
        prev_min = -1
        if self.use_brightness_sensor:
            sensorMax = 100.0
            sensorCurrent = 120.0
            brightnessMin = 50.0
            brightnessMax = 255.0

            self.brightness_mode_pos = min(((((brightnessMax - brightnessMin) / sensorMax) * sensorCurrent) + brightnessMin),255)

        while True:
            # Get current time
            now = datetime.datetime.now()
            newBrightness = self.brightness_mode_pos
            if self.use_brightness_sensor:
                try:
                    sensorCurrent = self.sensor.lux
                    if isinstance(sensorCurrent, float):
                        # print('sensorCurrent is ' + str(sensorCurrent))
                        newBrightness = min(((((brightnessMax - brightnessMin) / sensorMax) * sensorCurrent) + brightnessMin),255)
                        newBrightness = int(newBrightness)
                        time.sleep(0.2)
                except IOError as e:
                    print(e)
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

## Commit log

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2015-01-10 Updated default plugin to display time
    [wordclock_config.example.cfg]
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2015-01-15 Added rss-feed-parser to get latest news
    [wordclock_config.example.cfg]
2015-02-04 Added interface class to wordclock
    [wordclock_config.example.cfg]
2015-02-04 Added concept of button-lock time
    A button cannot be pressed twice during a given time interval,
    which is passed as config-file parameter
    [wordclock_config.example.cfg]
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2015-02-18 Fix to properly support swabian mode...
    [plugin.py]
2015-02-18 plugins wcb-use corrected tp wci-usage
    [plugin.py, time_swabian.py]
2015-02-22 Added various stancil layouts
    Based on the layouts, provided by Caglar
    [wordclock_config.example.cfg]
2015-04-12 Added draft of dutch layout (UNTESTEDgws
    ... before you order a stancil, please assure the correct layout.
    [wordclock_config.example.cfg]
2015-06-04 Minor enhancements
    ... for improved useability.
    [wordclock_config.example.cfg]
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2015-11-13 Added config-file based brightness control
    ... tested with https://github.com/jgarff/rpi_ws281x
    at commit 2f9e03c45ba0964029204db565ad9d6233b3a1a6
    [wordclock_config.example.cfg]
2015-11-18 Added activation bool to all plugins
    [wordclock_config.example.cfg]
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2015-12-12 Fixed wiring documentation
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2015-12-27 Added support for temperature sensor
    ... usable to measure indoor temperature.
    [wordclock_config.example.cfg]
2015-12-27 Updated wiring concept (contains now temperature sensor)
    [wiring.xlsx]
2015-12-27 Quick-fix for temperature sensor
    [plugin.py]
2015-12-31 Fixed weatherforecast plugin
    Thanks to SEBatHome ;)
    [plugin.py]
2016-03-11 Add language Swiss German
    Add Swiss German 11x10 layout and update plugins time_default,
    time_matrix and sunrise
    [wordclock_config.example.cfg]
2016-03-19 Implemented wiring options for buttons
    To run the wordclock without connected buttons
    [wordclock_config.example.cfg]
2016-03-30 Update wiring.py
    Just a small one but this wrong description could lead to misunderstandings.
    [wiring.py]
2016-08-03 Added new plugin to display current ip address
    [wordclock_config.example.cfg]
2016-08-03 Added typewriter animation to time_default plugin
    Also: Minor fixes in feed_parser
    [wordclock_config.example.cfg]
2016-08-21 Updated typewriter functionality
    ... only applied every 5 minutes.
    [wordclock_config.example.cfg]
2016-09-10 Added instructions to disable RPis soundcard
    ... in case the LEDs do not work correctly.
2016-10-02 Fixed typo
    Thanks to ulab
    [wordclock_config.example.cfg]
2016-11-08 Fixed display of wrong colors.
    [wordclock_display.py]
2016-11-11 First upload of second swiss german dialect.
    [wordclock_config.example.cfg]
2016-11-11 Fixing the swiss_german2 dialect
    [plugin.py]
2016-11-15 Added STL files to 3D print the LED base for NeoPixel Strip 5m (WS2812B - black PCB) 30LED/m.
    [LED Base - LED Mount BL.stl, LED Base - LED Mount BM.stl, LED Base - LED Mount BR.stl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]
2016-11-16 added virtual buttons for remote to work
    [wordclock_config.example.cfg]
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2016-11-25 Resetted example config-file to proper defaults.
    [wordclock_config.example.cfg]
2016-12-05 Fixing two "typos" in swiss_german2
    [time_swiss_german2.py]
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2016-12-20 Quick fix for button press
    [wordclock_interface.py]
2017-01-02 Update doc_software_setup.rst
    Fixed dependency to readout temperature sensor.
2017-01-11 Adding Dutch 11x10
    Adding Dutch 11x10
    [wordclock_config.example.cfg]
2017-02-02 fixed gpio input once more
    [gpio_interface.py]
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2017-02-09 event handler: replacement for sleep
    [event_handler.py]
2017-03-30 Added missing plugin description
    [plugin.py]
2017-08-30 Added alternative german layout
    [wordclock_config.example.cfg]
2017-10-31 Fixed a typo upstream which was fixed locally a long time ago
    [time_swiss_german2.py]
2017-10-31 Adopted leds_off_plugin to latest wordclock version
    [wordclock_config.example.cfg]
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2017-12-18 Fixed missing gpio-type
    [wordclock_config.example.cfg]
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2018-02-06 Wordclock now shows IP at startup
    [wordclock_config.example.cfg]
2018-02-19 Fix for issue #85
    [wiring.py]
2018-03-03 Fix to ensure language to be string-type
    Addresses #86
    [plugin.py]
2018-05-01 "HALF" in Dutch not displayed correctly
    In Dutch the word "HALF" is shifted too far to the right.
    [time_dutch.py]
2018-05-17 very simple gtk emulator, breaks normal operation
    # Conflicts:
    # wordclock.py
    # wordclock_tools/wiring.py
    [wordclock_config.example.cfg]
2018-06-10 Fix for default display mode
    [wordclock_display.py]
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2018-06-23 Updated webinterface and handling of developer mode
    [wordclock_config.example.cfg]
2018-10-20 Fixed wrong mapping of color channels
    [wordclock_display.py]
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2018-10-26 Fix to make brightness change visible
    [wordclock_display.py]
2018-10-26 Fixed color request via API
    [web_interface.py]
2018-10-26 Fixed color requrest via API for dev + production env
    [web_interface.py]
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2018-11-20 sleep mode added to time_default plugin
    [wordclock_config.example.cfg]
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2019-01-12 Fixes for color temperature
    [web_interface.py, wordclock_colors.py]
2019-02-16 added fix for brocken pixel
    [wiring.py]
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2019-02-17 added config to remotely maintain the shit
    [wordclock_config.cfg]
2019-02-17 updated config to new language handling
    [wordclock_config.cfg]
2019-02-17 corrected indent
    [wordclock_config.cfg]
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2019-02-25 try to fix double 59
    [plugin.py]
2019-02-27 Minor fix in seconds plugin
    [plugin.py]
2019-09-09 custom font is finished
    text is shown in same height now
    added custom font: wcfont.ttf
    [wordclock_config.example.cfg]
2019-09-15 Added no_gpio as interface type.
    This disables any readout of gpio pins (which are used to detect, if a button was pressed).
    Use this, if no buttons are attached to the clock.
    [wordclock_config.example.cfg]
2019-09-16 Update wordclock_display.py
    fixed indent
    [wordclock_display.py]
2019-09-16 Update wordclock_display.py
    fixed if statement
    [wordclock_display.py]
2019-09-29 Fix to make FreeSans work again
    [wordclock_display.py]
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2019-10-31 WIP
    Replace Color-function from neopixel with own implementation of Color-class
    ... to make transitions work
    [GTKstrip.py, plugin.py, wiring.py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]
2019-10-31 Fix to make new color handling work
    [wordclock_colors.py, wordclock_display.py, wordclock_screen.py]
2019-11-01 Updates and fixes for transitions
    [plugin.py, web_interface.py, wordclock_display.py]
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2020-01-26 Fix to make dev-mode work with transitions
    improvement of brightness handling required to allow fading to 0 and back to 255
    [wordclock_colors.py, wordclock_display.py]
2020-02-07 House keeping
    Replaced print with logging
    [plugin.py]
2020-09-25 Fix for Matrix_Time plugin
    Fixes issue #146: incorrect indentation.
    [plugin.py]
2021-01-11 Fix for home assistant integration
    [web_interface.py, wordclock_display.py]
2021-01-14 Fixes to ensure proper home assistant integration
    [wordclock_display.py]
2021-04-07 Add default colors in the config
    [wordclock_config.example.cfg]
2021-04-07 Add missing plugins in example config
    [wordclock_config.example.cfg]
2021-04-08 Move default colors config in plugin_time_default
    [wordclock_config.example.cfg]
2021-04-08 Add ability to choose the order of the minutes
    [wordclock_config.example.cfg]
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2021-07-24 House keeping and minor bug fixes
    [wordclock_config.example.cfg]
2021-07-25 Fixed sunrise plugin
    [wordclock_config.example.cfg]
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2021-07-29 Fix error in wiring.py
    [wiring.py]
2021-07-29 Add activation of the snake plugin in the default config
    [wordclock_config.example.cfg]
2021-07-29 Add ability to choose no animation when displaying the time
    [wordclock_config.example.cfg]
2021-07-29 Add ability to set the animation speed in the config
    [wordclock_config.example.cfg]
2021-08-16 Add changes of PR #201, credits @phenze
    This commit holds changes of PR #201 with squashed history.
    PR was indicating a (confusing/misleading number of 9288 lines of code...)
    Credits to @phenze
    [wordclock_config.example.cfg]
2021-08-17 Refactored handling of config values
    Config values are parsed and cached in wordclock_config.py.
    When a config value is requested,
    value is extracted from wordclock_config.cfg.
    If not available, extraction defaults to wordclock_config.reference.cfg
    [wordclock_config.reference.cfg]
2021-08-17 Fixed mergeconflict
    [wordclock_config.reference.cfg]
2021-08-17 Adopted wordclock plugins to new config handling
    [wordclock_config.reference.cfg]
2021-08-18 added setting for not animating every second
    [wordclock_config.reference.cfg]
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2021-11-01 Update web_interface.py
    Fix for a last minute change....
    [web_interface.py]
2021-11-01 Update web_interface.py
    Fix for last minute change......
    [web_interface.py]
2021-11-20 OpenWeatherMap
    Pywapi replaced by OpenWeatherMap.
    Fixes #163
    [wordclock_config.reference.cfg]
2021-12-14 basic implentation of swedish word clock
    [wordclock_config.reference.cfg]
2021-12-14 fixed swedish chars
    [wordclock_config.reference.cfg]
2022-01-23 Additional configuration for brightness sensor
    Possibility to configure the address of the sensor in the config file.
    Related to #214 .
    [wordclock_config.reference.cfg]
2022-08-01 add romanian language option
    [wordclock_config.example.cfg]
2022-08-24 Minor fixes for swedish layout
    [wordclock_config.reference.cfg]
2022-08-24 Fix in snake plugin
    [plugin.py]
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

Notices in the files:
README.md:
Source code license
